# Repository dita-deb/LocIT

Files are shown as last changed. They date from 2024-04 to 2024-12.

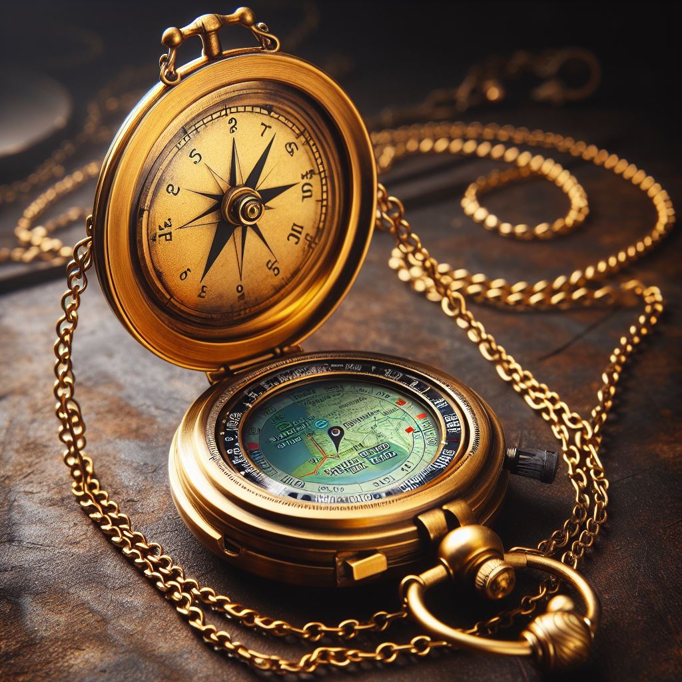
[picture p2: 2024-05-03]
3D Renders/Proposal/compasscam.jpg

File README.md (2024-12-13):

# LocIT
Senior Design Project 2024  

## Overview  
LocIT, short for "Location Integrated Tracker," is a wearable safety device designed to enhance the security and monitoring of vulnerable individuals, such as children and elderly users. This project addresses real-world safety concerns with an innovative combination of hardware and software, offering real-time location tracking, facial recognition, geofencing, and more.

## Features  
- **GPS Location Tracking**: Accurate updates every 30 seconds with a 3-foot precision.
- **Temperature Monitoring**: Prevents device overheating by triggering shutdowns of non-essential components.
- **Vibrating Alerts**: Provides real-time notifications for geofence breaches or caregiver messages.
- **Gyroscope and Accelerometer**: Detects sudden movements or falls, notifying caregivers instantly.
- **Facial Recognition**: Identifies individuals near the wearer for added safety insights.
- **Geofencing**: Sends alerts when the user exits predefined safe zones.
- **Companion App**: Supports live tracking, notifications, and settings customization via FlutterFlow.

## Hardware System  
- **Sensors Subsystem**: Includes GPS, temperature, battery monitor, accelerometer, and gyroscope.
- **Actuators Subsystem**: Utilizes a vibration motor for silent notifications.
- **Communications Subsystem**: Transfers data securely via MQTT to AWS IoT Core and DynamoDB.
- **Power Subsystem**: Powered by a rechargeable LiPoly battery with over 24 hours of operation.
- **Central Processing Unit**: Raspberry Pi Zero 2 W for managing data, algorithms, and communication.

## Software System  
- Python-based main algorithm managing data collection, device state, and communication.
- AWS integration for real-time data storage and retrieval. [Backend-Webserver](https://02fydzyygd.execute-api.us-east-2.amazonaws.com/LocITDynamoDBDisplay)
- Companion app (FlutterFlow) for monitoring and control.

## Encasing Design  
- Constructed from PLA filament with 2 mm thickness for strength and durability.
- Compact dimensions: 2 inches wide, 4 inches long, and 2 inches deep.
- Three lid variations:
  - **No Slots Lid**: For fully enclosed design.
  - **4 Vents Lid**: Balanced ventilation and enclosure.
  - **9 Vents Lid**: Maximum cooling for high-temperature environments.

## Results  
- **High Accuracy**: GPS provides precise location tracking within a 3-foot radius.
- **Reliable Notifications**: Geofence breaches and fall detection alerts are delivered promptly.
- **Extended Usability**: Optimized power management ensures operation over a full day.

## Improvements and Optimizations  
Future enhancements include:
- Advanced facial recognition models for diverse conditions.
- Improved companion app usability with push notifications.
- Additional sensors for expanded functionality (e.g., heart rate monitoring).

## Getting Started  
Visit the [LocIT GitHub Repository](https://github.com/dita-deb/LocIT) for source code, hardware schematics, and additional documentation.

## License  
This project is licensed under a custom license. Redistribution, modification, or commercial use is restricted without explicit permission from the contributors. See the [LICENSE](LICENSE) file for more details.

## Contributors  
- **Anindita Deb** (dita-deb)  
- **Zachary Ponder** (ponder-zachary)  
- **Avery Porter** (Averyp119)
- **Damisi Kayode** (DamisiKayode0312)

## Acknowledgments  
Special thanks to Professor Jeffrey L. Yiin at Kennesaw State University for guidance and mentorship throughout the project.

---

*LocIT: Bringing peace of mind to caregivers while ensuring the safety of their loved ones.*

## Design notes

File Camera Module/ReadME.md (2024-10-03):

# Camera Module
## Contains: camera imaging and processing 
### Materials:
- Pi Camera (2)
- RaspberryPi 3B+ or 4B
- Gyroscope
- Servo Motor
- 3D print Holder

### Proposal Folder
- Contains initial plans for the Senior Project Proposal
- Contains a work in progress facial expressions recognition files

### Facial Recognition for PC
- This contains the python code to run this model on Visual Studio Code

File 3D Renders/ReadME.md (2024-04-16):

# 3D Renders
## File contains:
- 3D models of pendant
- 3D models for Camera holder
- additional files..

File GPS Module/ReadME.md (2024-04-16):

# GPS Module
## Materials:
- TinyDuino Processor Board
  - Lithium Battery Support
- USB TinyShield
- Flash Memory TinyShield
- GPS TinyShield
- Mounting Kit
- Lithium Ion Polymer Battery - 3.7V 270mAh

## Website reference:
https://www.instructables.com/Tiny-GPS-Tracker/

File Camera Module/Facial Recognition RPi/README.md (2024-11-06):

# Facial Recognition on Raspberry Pi Zero 2W
## Materials 
- Pi Zero 2W
- PiCamera Module 3
Arducam Multi-Camera Header
## Set Up Environment
### Install Despendencies
- sudo apt update
- sudo apt install python3-opencv python3-picamera2
## Code Files
- face_taker.py
- face_train.py
- face_recognizer.py
## Notes:
### Key Adjustments Summary
- Replaced cv2.VideoCapture with Picamera2 to utilize the Raspberry Pi Camera Module.
- Modified the image capture and display logic to ensure compatibility with the Pi’s performance limitations.

- Performance Optimization: Reduce the detectMultiScale parameters (scaleFactor and minNeighbors) if performance is slow.
- Testing: Test each script independently to ensure smooth functionality. The Raspberry Pi Zero 2 W has limited power, so patience and optimizations may be necessary.

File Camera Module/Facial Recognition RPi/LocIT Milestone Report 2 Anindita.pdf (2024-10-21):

### LocIT Milestone #2 Report Update by Anindita Deb

Date: 09/21/2024 - 10/20/2024

Advancements Made Since Milestone 1
Facial Recognition Enhancements:
- Improved the facial recognition accuracy when detecting multiple faces:
- Initially, the system could only recognize one person in the frame.
- Progressed to tracking two people, but inaccurately. NotWorking_with_Sister.mov (https://kennesawedu.sharepoint.com/:v:/r/sites/Team-CpESeniorProject2024/Shared%20Documents/General/Milestone%20Presentations/Milestone%202%20Presentation/Not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)

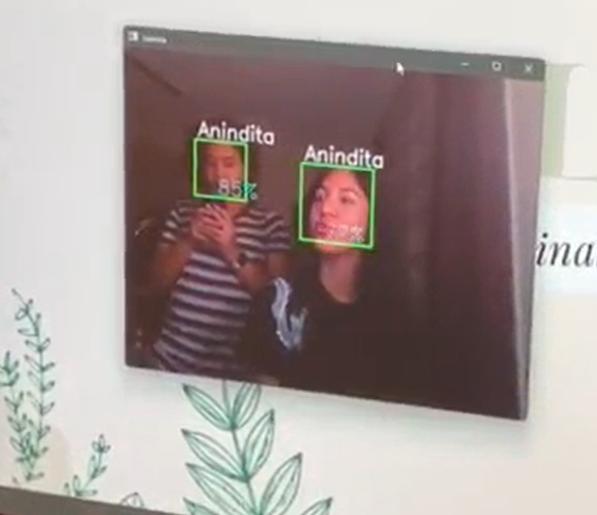
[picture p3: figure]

- Achieved successful tracking of two people. Working_with_Roommate.mov (https://kennesawedu.sharepoint.com/:v:/r/sites/Team-CpESeniorProject2024/Shared%20Documents/General/Milestone%20Presentations/Milestone%202%20Presentation/Wor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)

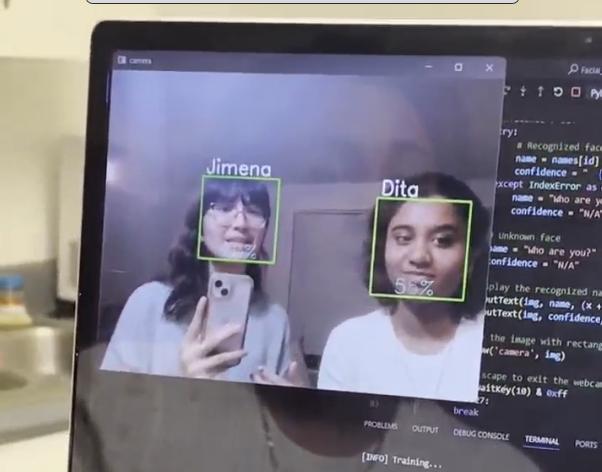
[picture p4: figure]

- Currently increased the capability to accurately track three people in a frame. zach-avery-dita.mov (https://kennesawedu.sharepoint.com/:v:/r/sites/Team-CpESeniorProject2024/Shared%20Documents/General/Milestone%20Presentations/Milestone%202%20Presentation/zac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)

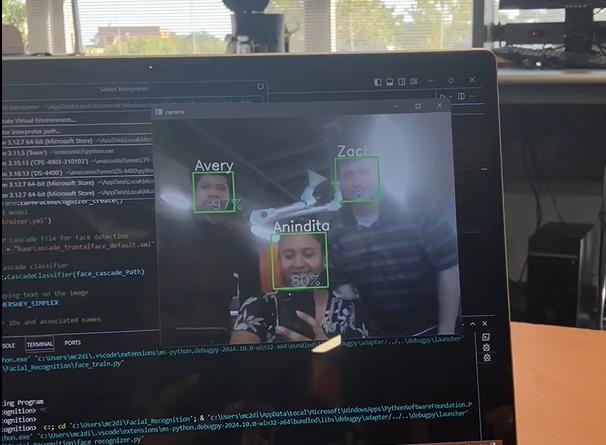
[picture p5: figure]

We tried it with the full group, but it was difficult to judge the accuracy of capturing all four of us in the frame. The pc camera was not catching everyone in the frame and would bounce between multiple people to track. I’ll cap it at 3 faces in frame being tracker when camera is on.
Camera Setup and Functionality:
- Configured the Raspberry Pi camera to detect faces and box them effectively.
- face-detection.mov (https://kennesawedu.sharepoint.com/:v:/r/sites/Team-CpESeniorProject2024/Shared%20Documents/General/Milestone%20Presentations/Milestone%202%20Presentation/fac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)
- face-detection-minimal-light.mov (https://kennesawedu.sharepoint.com/:v:/r/sites/Team-CpESeniorProject2024/Shared%20Documents/General/Milestone%20Presentations/Milestone%202%20Presentation/fac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)
- face-detection-darkness.mov (https://kennesawedu.sharepoint.com/:v:/r/sites/Team-CpESeniorProject2024/Shared%20Documents/General/Milestone%20Presentations/Milestone%202%20Presentation/fac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)
- Encountered issues with the labeling system, which is not functioning correctly.
- I suspect it’s the libraries not updating correctly per Raspberry Pi Model.
- I’ll be trying multiple existing models that have proven to work on Raspberry Pi to test and work it out in the coming milestone.
- The face_taker.py file is not yet operational for automatically capturing and saving the user’s face.
- The user needs to enter a name (which becomes a folder holding all images of that individual in the database)

- The Pi then asks the user to manually press a key on the keyboard to take a picture and it is saved to the designated folder
face-taker-not-automated.mov (https://kennesawedu.sharepoint.com/:v:/s/Team-CpESeniorProject2024/ESrZX5XtYEpOoALUHIoNt6YBmQBpAaYaH6LICQdui1YwaA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)

Integration of Models:
- Working on combining the facial recognition and expression monitoring models.
- Then placing it onto the pi camera.
- This integration process is taking additional time due to the need for compatible libraries for the Raspberry Pi.
- Once I’ve installed the models onto the pi, I’ll have it connected to AWS to active the camera remotely and store pictures off of the device to save storage.

Overview of Prior Work
As previously reported, the focus of the project includes this previous report:

### LocIT Milestone #1 Report by Anindita Deb

08/18/2024 - 09/20/24

Overview
I oversee the facial recognition software implemented in LocIT. Using various machine learning models, I aim to create a system capable of recognizing individuals and addressing multiple functionalities, including:
- Recognizing familiar faces
- Flagging unknown faces during significant interactions
- Identifying conditions that trigger a significant interaction
- Flagging certain facial expressions
- Angered/upsetting expressions could imply that the LocIT user is in a potentially unsafe situation
- Tracking negative expressions is a key feature being developed to alert the user to potential risks, improving situational awareness and safety
- Addressing additional issues like sleep/awakening conditions
- Limiting battery strain
- Handling privacy concerns

Facial Recognition Development
I’ve updated the code for this portion of the project to the GitHub Project page (https://github.com/dita-deb/LocIT/tree/main/Camera%20Module/Facial_Recognition_PC)

I wanted to eliminate the stress of collecting data through other means and inserting it into the model for training for the user. There’s a built-in file that will take snapshots of the user for 30 seconds (1 frame per second) to train the model to recognize the user.

Here is a break down of each individual file and its application to the overall model: Face_taker.py: Captures images of the target individual and stores them in the dataset for later use in training the model.
Face_train.py: Trains the facial recognition model using the images captured in Face_taker.py, allowing the system to recognize the individual’s face.
face_recognizer.py: Runs the trained facial recognition model, identifying individuals from the dataset in real-time or from new images.
names.json: Stores a mapping between each individual's name and their corresponding image data in the dataset.
haarcascade_frontalface_default.xml: A pre-trained Haar Cascade classifier that detects facial features (e.g., eyes, nose, mouth) to identify and classify faces for recognition.

The way that it displays a recognized face is by drawing a green box around the face and having the person labeled with a certain amount of confidence as shown below:

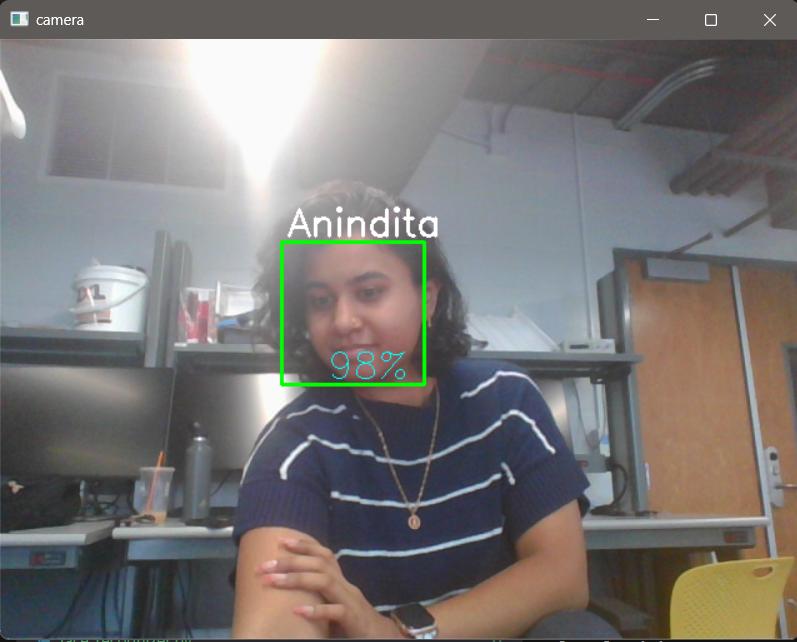
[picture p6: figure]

These just screen shots of a live video feed; I have a converter (video to image parser) not yet added to the model because there is yet to add a storage system to save these images and files for someone to view later. This will be a Milestone 2 issue, handling data and its storage and manipulation from the app.

Facial Expressions Development

I’ve updated the code for this portion of the project to the GitHub page (https://github.com/dita-deb/LocIT/tree/main/Camera%20Module/Proposal)

This phase of the project focuses on calculating a person’s eye gaze direction and blink rate, which form the initial part of addressing the expressions challenge.
These two factors—gaze direction and blink rate—are key indicators of whether a person is attentive or distracted. This classification helps determine how individuals around the LocIT wearer engage with them, affecting social interactions and spatial awareness.

The model uses Haar cascades to detect facial features, followed by PERCLOS for blink rate analysis, and geometric methods for gaze direction estimation.

Additionally, I plan to implement a system for tracking negative or threatening expressions. By flagging such expressions, the system can alert the wearer to potential risks, enhancing their safety and situational awareness. This is also not yet implemented to the hardware or Application yet, as it is a milestone 2 issue.

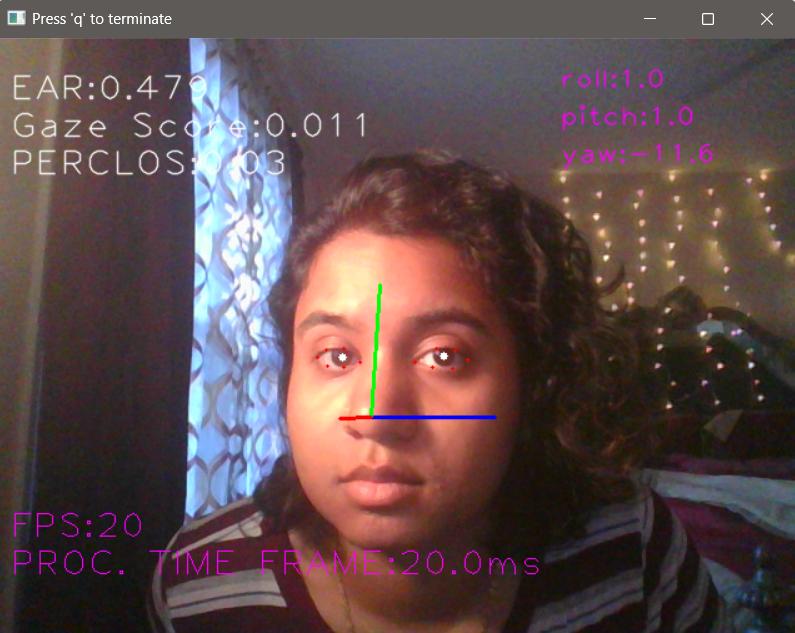
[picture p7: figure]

Here is a sample of what this model does:

The measurements here are displayed to check whether the model is working or not with “maths” that calculates tiredness/distraction/paying attention etc. This math is pre-built into the base model which I’m just changing some values to better check and flag certain expressions.

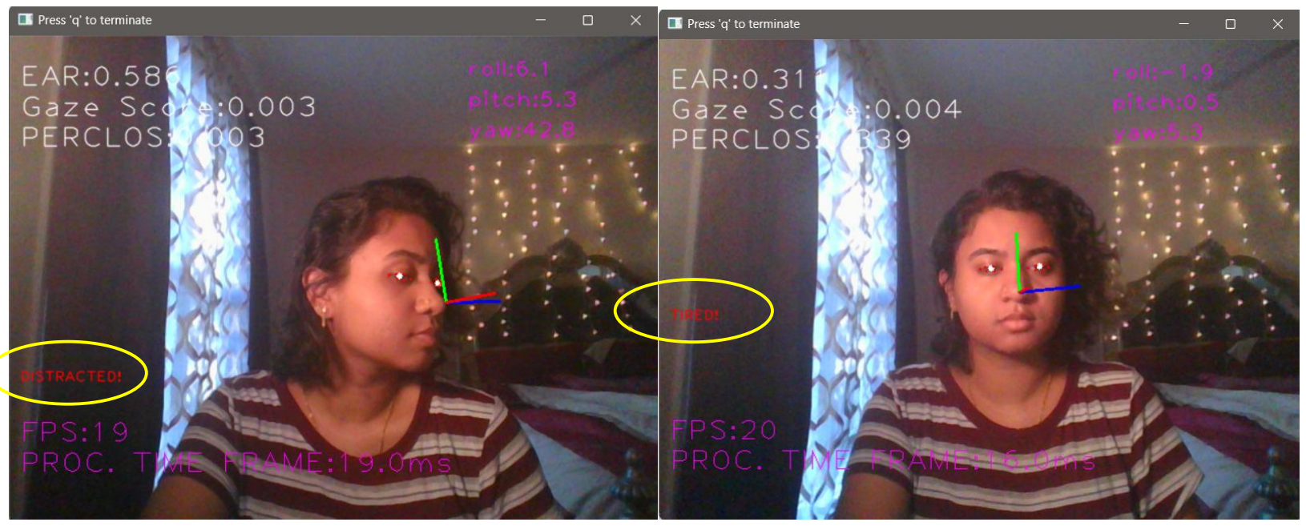
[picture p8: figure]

These images show a red text labeled “Distracted” and “tired” which can flag the interaction in different situations. Even if there is a person in front of the LocIT it would not flag the interaction as anything dangerous for the user or demand the individual be added to the dataset.
Software to Hardware Integration
The software to hardware implementations are in development as the model requires better storage for the images and video stream.

I have started using the Raspberry Pi 4B+, 2 PiCam Noir 3 Wide Module and ArduCam Header for implementation setup.

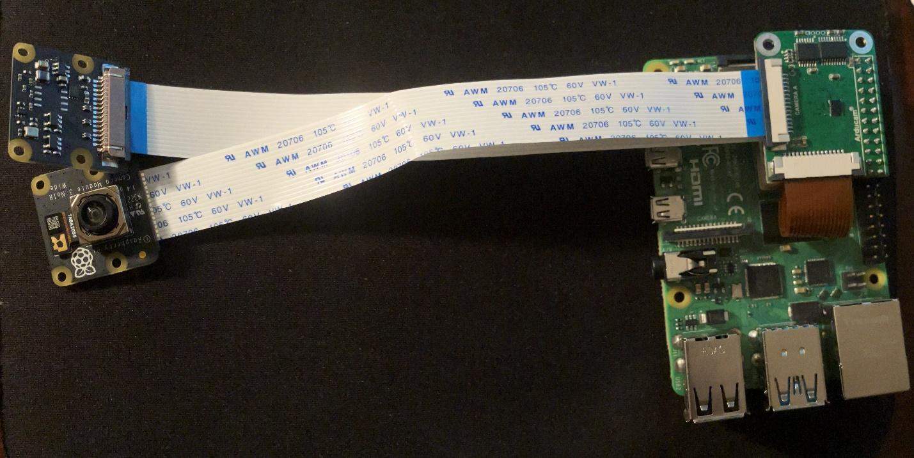
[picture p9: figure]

This is the set up, the cameras and header on the raspberry pi 4b+ are also compatible with the RaspberryPpi Zero 2 W. I’m using this board mainly as a way to quickly check the model working rather than than the Zero 2 board as a way to avoid any SW/HW issues that may come up when creating the final product.

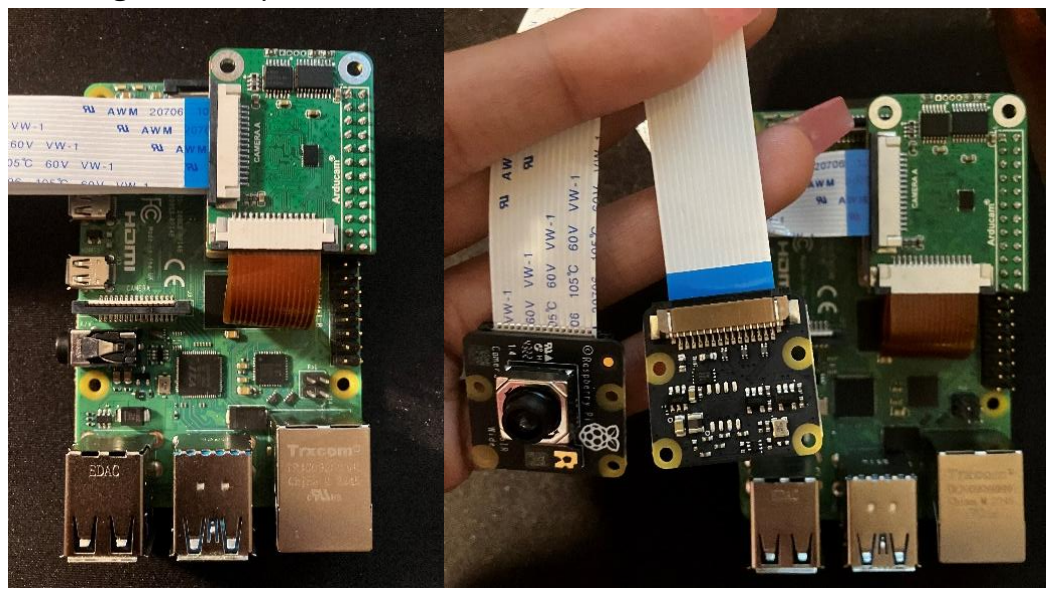
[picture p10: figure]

The ArduCam header allows me to connect 2 cameras to the Pi and have it checking whether there is a feed coming through one side or not to turn off a camera or not depending on the side that has live feed. The Pi on it’s own only allows one camera to operate at a time. This header allows for multiple cameras with a single component addition that is sized to fit the Pi Zero 2 W perfectly.

Issues/Challenges
IoT AWS implementation is going to be what our next milestone will encompass. The App development will also play a large part in data collection/storage/display for the next milestone. The integration portion of the hardware to software will be our biggest hurdle in the upcoming weeks.

Additional Information
Any additional information will be provided by the other reports.

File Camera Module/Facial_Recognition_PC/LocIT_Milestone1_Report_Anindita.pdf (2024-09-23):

### LocIT Milestone #1 Report by Anindita Deb

08/18/2024 - 09/20/24

Overview
I oversee the facial recognition software implemented in LocIT. Using various machine learning models, I aim to create a system capable of recognizing individuals and addressing multiple functionalities, including:
- Recognizing familiar faces
- Flagging unknown faces during significant interactions
- Identifying conditions that trigger a significant interaction
- Flagging certain facial expressions
- Angered/upsetting expressions could imply that the LocIT user is in a potentially unsafe situation
- Tracking negative expressions is a key feature being developed to alert the user to potential risks, improving situational awareness and safety
- Addressing additional issues like sleep/awakening conditions
- Limiting battery strain
- Handling privacy concerns

Facial Recognition Development
I’ve updated the code for this portion of the project to the GitHub Project page (https://github.com/dita-deb/LocIT/tree/main/Camera%20Module/Facial_Recognition_PC)

I wanted to eliminate the stress of collecting data through other means and inserting it into the model for training for the user. There’s a built-in file that will take snapshots of the user for 30 seconds (1 frame per second) to train the model to recognize the user.

Here is a break down of each individual file and its application to the overall model: Face_taker.py: Captures images of the target individual and stores them in the dataset for later use in training the model.
Face_train.py: Trains the facial recognition model using the images captured in Face_taker.py, allowing the system to recognize the individual’s face.
face_recognizer.py: Runs the trained facial recognition model, identifying individuals from the dataset in real-time or from new images.
names.json: Stores a mapping between each individual's name and their corresponding image data in the dataset.
haarcascade_frontalface_default.xml: A pre-trained Haar Cascade classifier that detects facial features (e.g., eyes, nose, mouth) to identify and classify faces for recognition.

The way that it displays a recognized face is by drawing a green box around the face and having the person labeled with a certain amount of confidence as shown below:

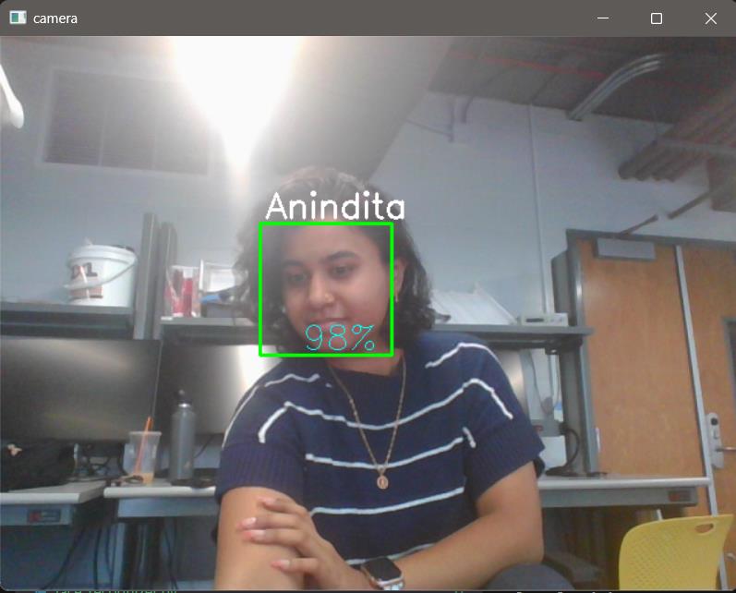
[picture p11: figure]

These just screen shots of a live video feed; I have a converter (video to image parser) not yet added to the model because there is yet to add a storage system to save these images and files for someone to view later. This will be a Milestone 2 issue, handling data and its storage and manipulation from the app.

Facial Expressions Development
I’ve updated the code for this portion of the project to the GitHub page (https://github.com/dita-deb/LocIT/tree/main/Camera%20Module/Proposal)

This phase of the project focuses on calculating a person’s eye gaze direction and blink rate, which form the initial part of addressing the expressions challenge.
These two factors—gaze direction and blink rate—are key indicators of whether a person is attentive or distracted. This classification helps determine how individuals around the LocIT wearer engage with them, affecting social interactions and spatial awareness.

The model uses Haar cascades to detect facial features, followed by PERCLOS for blink rate analysis, and geometric methods for gaze direction estimation.

Additionally, I plan to implement a system for tracking negative or threatening expressions. By flagging such expressions, the system can alert the wearer to potential risks, enhancing their safety and situational awareness. This is also not yet implemented to the hardware or Application yet, as it is a milestone 2 issue.

Here is a sample of what this model does:

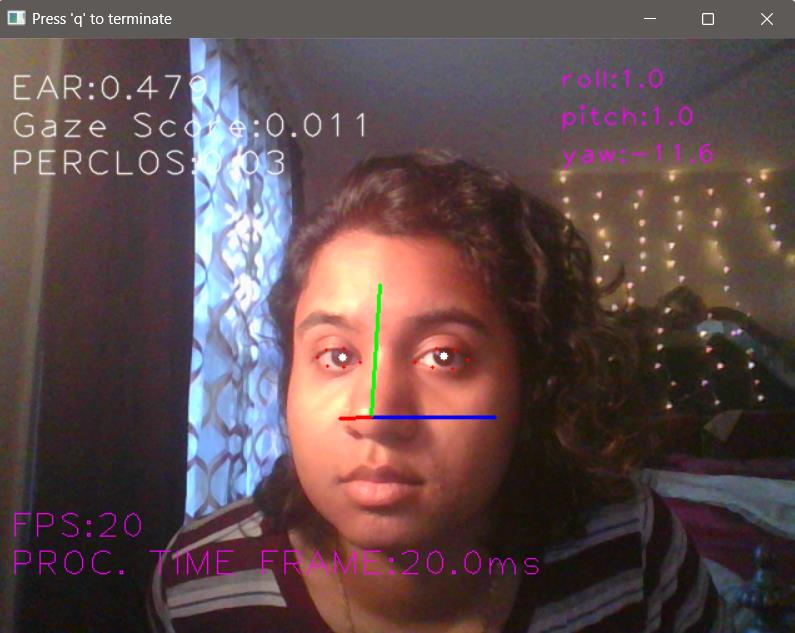
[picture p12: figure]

The measurements here are displayed to check whether the model is working or not with “maths” that calculates tiredness/distraction/paying attention etc. This math is pre-built into the base model which I’m just changing some values to better check and flag certain expressions.

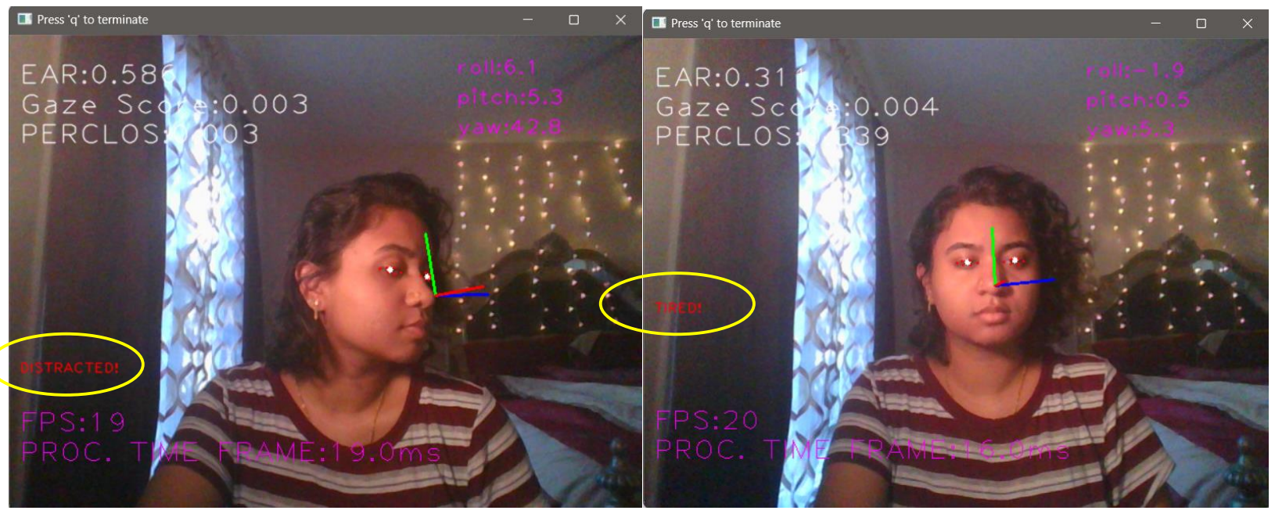
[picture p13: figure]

These images show a red text labeled “Distracted” and “tired” which can flag the interaction in different situations. Even if there is a person in front of the LocIT it would not flag the interaction as anything dangerous for the user or demand the individual be added to the dataset.

Software to Hardware Integration
The software to hardware implementations are in development as the model requires better storage for the images and video stream.

I have started using the Raspberry Pi 4B+, 2 PiCam Noir 3 Wide Module and ArduCam Header for implementation setup.

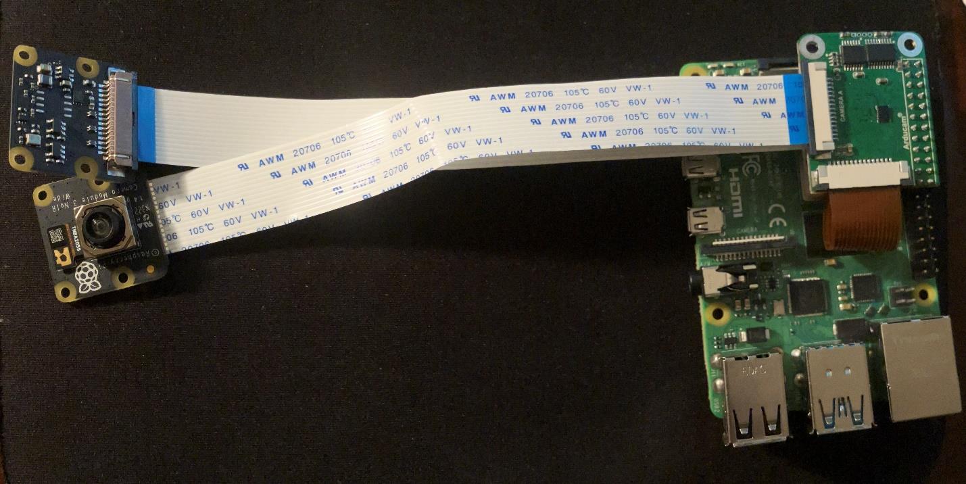
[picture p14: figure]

This is the set up, the cameras and header on the raspberry pi 4b+ are also compatible with the RaspberryPpi Zero 2 W. I’m using this board mainly as a way to quickly check the model working rather than than the Zero 2 board as a way to avoid any SW/HW issues that may come up when creating the final product.

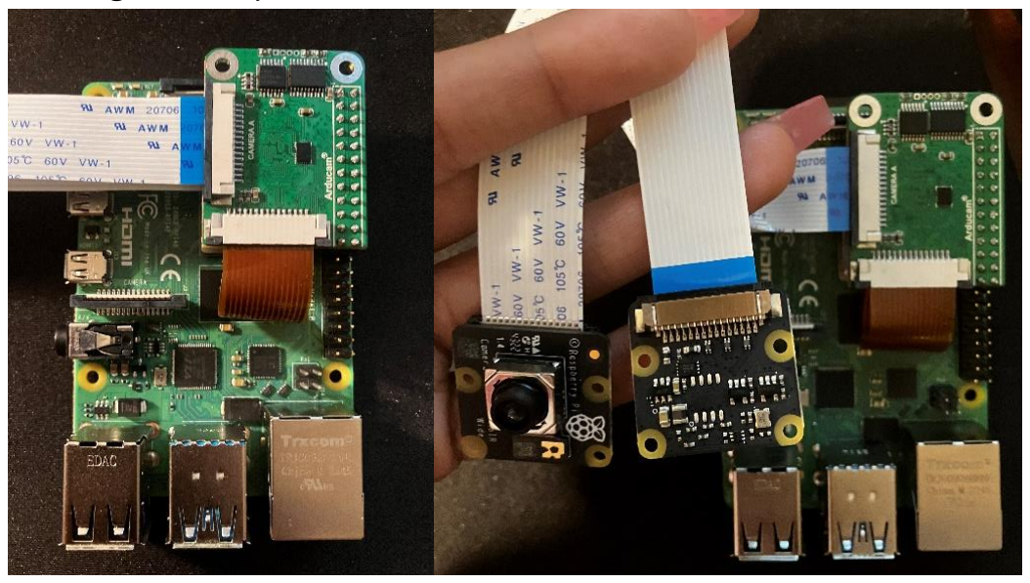
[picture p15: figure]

The ArduCam header allows me to connect 2 cameras to the Pi and have it checking whether there is a feed coming through one side or not to turn off a camera or not depending on the side that has live feed. The Pi on it’s own only allows one camera to operate at a time. This header allows for multiple cameras with a single component addition that is sized to fit the Pi Zero 2 W perfectly.

Issues/Challenges
IoT AWS implementation is going to be what our next milestone will encompass. The App development will also play a large part in data collection/storage/display for the next milestone. The integration portion of the hardware to software will be our biggest hurdle in the upcoming weeks.

Additional Information
Any additional information will be provided by the other reports.

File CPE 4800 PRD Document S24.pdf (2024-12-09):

## CPE 4800 - Senior Design Proposal, Spring 2024

# Product Requirements Document

## LocIT

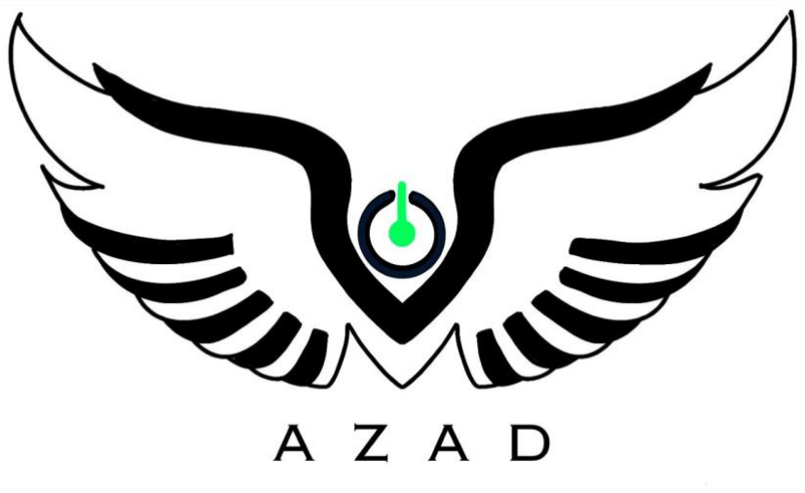
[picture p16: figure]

## Rev. Number: Revision D

## Date: April 15, 2024

## Electrical and Computer Engineering

## Kennesaw State University

Faculty: Dr. Jeffrey L Yiin

Product Requirements Document

## Revision History

Name | Date | Reason For Changes | Version
AZAD | 03-31-2024 | Initial Release | Rev. - Draft
AZAD | 04-15-2024 | Updated minor changes to the following: revision history, I. Introduction, and II. Product specifications Major changes to the following: Table of Contents, List of Figures, List of Tables, III. System Architecture, Bill of Materials, Product Requirements, and Bibliography | Rev. - A
AZAD | 10-21-2024 | Bluetooth functionality has been added to the feature set. Ultraviolet sensors have been removed from the design due to excessive procurement lead times. | Rev. - B
AZAD | 10-23-2024 | Updated product requirements to remove any instances of ultraviolet sensors and adding Bluetooth requirements. | Rev. - C
AZAD | 11-16-2024 | Adjusted product requirements to account for changes that were made to the prototype given the scope of the project. | Rev. - D

## Table of Contents

## List of Figures

Total List of Figures

Figure Description | Section of PRD | Starting Page
Concept Prototype Renders | II. Introduction | Page 8
System Hardware Diagram | III. System Architecture | Page 15
Power Management Subsystem | III. System Architecture | Page 16
Camera Subsystem Diagram | III. System Architecture | Page 17
Software App Block Diagram | III. System Architecture | Page 18
Location Tracking Swimlane | III. System Architecture | Page 20
Facial Recognition Swimlane | III. System Architecture | Page 21
Geofencing Swimlane Diagram | III. System Architecture | Page 23
PCB Subsystem Diagram | IV. Product Requirements | Page 26
Microcontroller Subsystem | IV. Product Requirements | Page 28
Mobile App Subsystem Diagram | IV. Product Requirements | Page 29

## List of Tables

Current List of Tables

Table Title | Section of PRD | Starting Page
Functional Requirements | II. Product Specifications | Page 11
Bill of Materials | III. System Architecture | Page 23

## I. Introduction

1. High-level product description
This project aims to address a pressing need for families with young children and elderly members who need the accessibility and ease of locating their loved ones in real time. The proposed solution is a wearable tracker designed specifically for these demographics.
The primary goal is to provide families with peace of mind by offering a lightweight, rechargeable tracker that operates independently of cellular devices. This ensures constant access to the location of loved ones.
2. Key product feature sets
This project plans to include the following features in order to accommodate most of the target issues for the demographic.
1) Precision tracking allows the device to accurately track the user's location in real-time.
2) Solar-Powered recharging utilizes solar power ensuring sustainability and reduces dependency on traditional charging methods.
3) Cellular device independence allows the tracker to function autonomously, eliminating the need for a connected cellphone.
4) Facial recognition enhances security and assurance by identifying individuals who encounter the user.
5) Distance Monitoring will track distances covered by the user, providing insights into their movements.
6) Geofencing allows users to set boundaries within which the wearer can move, with alerts triggered if these boundaries are breached.
3. Value proposition to the customers
For families with young children and elderly members, peace of mind is invaluable. Our wearable tracker offers a solution tailored to your needs, providing constant access to the location of your loved ones without the need for a cellphone. With precision tracking and solar-powered recharging, you can rest assured knowing their whereabouts are always within reach. Our device goes beyond mere location tracking, incorporating facial recognition for added security and distance monitoring to keep you informed about their activities. Plus, with customizable geofencing, you can establish safe boundaries and receive alerts if they wander too far. Experience the reassurance of knowing your loved ones are safe and secure, no matter where they may be, with our innovative tracker.
4. Target Market Analysis
1. Target market size: annual shipment units and total sales revenue (worldwide or US market). There were nearly half a billion smart wearable devices sold worldwide in 2023. This includes over 305 million smartwatch units alone. The total revenue in the previous year equated to 45 billion dollars according to Statista.com¹
. The wearable
smart device market is expected to continue to grow as the post COVID pandemic

1 Statista Website: Historical Trends 2023, https://www.statista.com/topics/1556/wearable-technology/#dossier-chapter2

pushed lots of people to be more health oriented. This includes all markets, especially the Asia-Pacific one where people utilizing smart devices are expected to rise from 76% to over 94% by the end of the decade.
2. Existing competition: The smart wearable market is considered fragmented, by mordorintelligence.com²
, which is defined as a market that is highly competitive with many different competitors; however, there is no single entity taking the lion’s share of the sales. The two main competitors are the Apple AirTag and the Tile tracker. The strength of Apple is its name. Everyone everywhere knows the name Apple at this point, and purchasing items from them is always safe with a guaranteed high-quality product. Their weakness though is they prefer to push items only compatible with their products. In fact, it took a major court case in Europe to get them to transition away from the Lightning cable and to the more common USB-C for their charging ports. Tile is mainly used to keep track of items like a wallet, car keys, etc., but could be repurposed to track individuals. The weakness though, much with Apple, is that they require the user to also possess a cell phone which is not the purpose of our product. We strive to provide a service that allows people to keep track of the location of their loved ones whether they are carrying a phone with them or not.
5. Visual representation of the product
Conceptually we have a variety of options to consider for the compact and design of the product. First is a necklace with a pendant with two cameras on either side, which would turn on depending on the side that receives light. The arm band is at a good height on the body to be worn and for the camera to still capture images, though it is not as compact or extremely discrete. It also has no guarantee of staying put in one direction as the user would move around so that would make implementing a set number of cameras harder. A pin or brooch would be a nice alternative if the user does not mind reattaching the device to new outfits every time. A fanny pack/sling design would be stable and not require two cameras for image capturing; however, it is not as discrete or as compact as we would like it to be.

Taking in account the factors and issues with all the options available, we have settled with a pendant design that would include a camera near the hinge. A combination of ultraviolet sensors and a gyroscope would be capable of determining orientation of the pendant and turn on the appropriate front-facing camera on either side.

2 Mordor Intelligence, Wearable Trackers Market Share & Growth: https://www.mordorintelligence.com/industry-reports/wearable-technology-market

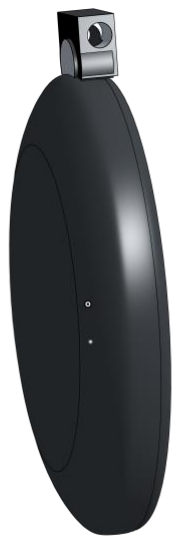
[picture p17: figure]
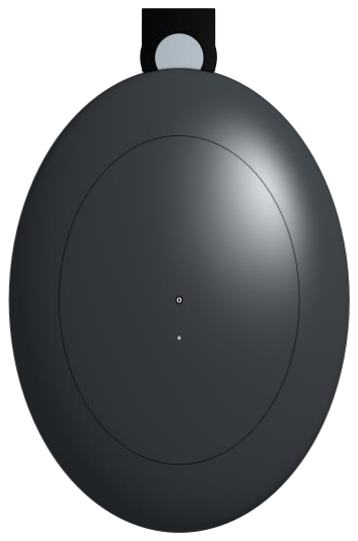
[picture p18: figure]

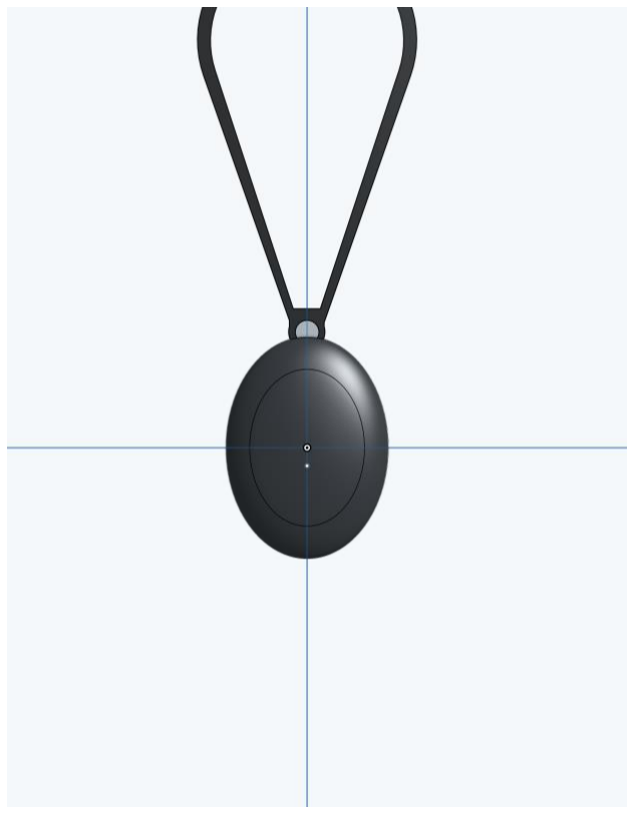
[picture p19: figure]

## II.Product Specifications

Requirement
ID
Description | Category | Priority

FNC-001 | The wearer tracker shall give an accurate location of the wearer within 3 feet of the wearer’s actual position. | Functional | Must Have
OPR-001 | The wearable tracker shall update the location at a regular interval of every 30 seconds. | Operational | Must Have
OPR-002 | The wearable tracker shall have a camera that is always capable of orienting towards the front and ensures image capturing in that direction. | Operational | Must Have
FAF-001 | The tracker will be able to measure the total distance travelled by the wearer over a given period of a day. | Fit and Form | Must Have
FNC-002 | The camera on the wearable tracker shall have facial recognition capabilities with the ability to recognize familiar faces. | Functional | Must Have
FNC-003 | The tracker will be integrated with voice assistance that can speak to the trackable wearer. | Functional | Nice to Have
FNC-004 | Users shall be able to set up or disable geocentric virtual boundaries for the wearer. | Functional | Must Have
FNC-005 | The application must send the host phone holder a notification if the wearable tracker leaves these boundaries. | Functional | Must Have
FNC-006 | The application shall send a notification to the host phone if the | Functional | Must Have

| battery level of the wearable tracker is below 20% remaining.
ENV-001 | The wearable tracker shall be chargeable using direct plug-in charging capabilities. | Enviromental | Must Have
ENV-002 | The wearable tracker shall prioritize Bluetooth connectivity over Wi-Fi when available, to optimize power efficiency and extend battery life. | Enviromental | Nice to Have
INT-001 | The companion app shall be able to be navigated by a user needing less than an hour of training on the app. | Interface | Must Have
INT-002 | The companion app shall utilize push buttons that allow the user to toggle between the various options (ie. Location, camera, geo-boundaries, notifications, settings) | Interface | Must Have
FNC-007 | The tracker shall utilize encryption techniques to securely connect between itself and the user’s companion application. | Functional | Must Have
NFC-001 | The tracker shall operate reliably under uncertain conditions such as change of habit, weather, or location. | Non-Functional | Must Have
PER-001 | The tracker must be able to handle simultaneous connections and data processes with a greater than 97% efficiency rate. | Performance | Must Have
NFC-002 | The host phone shall have the ability to add up to three wearable trackers on the companion application. | Non-Functional | Must Have

PER-002 | The companion app shall be able to connect and work seamlessly with both Android and Web devices. | Performance | Must Have
FAF-003 | The tracker shall be durable and resistant to water, dust, and fall protection. | Fit-and-Form | Must Have
FAF-004 | The wearable tracker shall feature a rectangular design with rounded corners to enhance safety and minimize the risk of injuries or accidents. | Fit-and-Form | Must Have
FAF-005 | The tracker shall weigh less than 15 grams³ to allow it to be worn comfortably. | Fit-and-Form | Must Have
FNC-008 | The tracker will allow for two-way communication between the companion app and wearer. | Functional | Nice to Have
INT-003 | The companion app will be accessible by supporting multiple different languages, including Spanish and French. | Interface | Nice to Have
INT-004 | The companion app will allow for customization, including changing the color palette. | Interface | Nice to Have
OPR-003 | The wearable tracker can monitor temperature to inform the wearer of dangerous outdoor conditions. | Operational | Nice to Have
OPR-004 | The wearable tracker will have the ability to monitor temperature to | Operational | Nice to Have

3 Avg. Weight of Necklace: https://fetchthelove.com/blogs/necklace/how-much-does-a-necklace-weigh-in-oz

| place the system in critical mode in the event of overheating.
FAF-006 | The wearable tracker will have a vibration notification system if another individual tries to communicate with the wearer. | Fit to Form | Nice to Have
OPR-005 | The wearable tracker will be able to go into low battery mode, which turns off all features except location and boundary tracking. | Operational | Nice to Have
FNC-009 | The wearable tracker will be able to store medical history information in a medical emergency. | Functional | Nice to Have
III. | System Architecture
Diagrams of System’s Functionality and External Interfaces:

System Hardware Block Diagram:

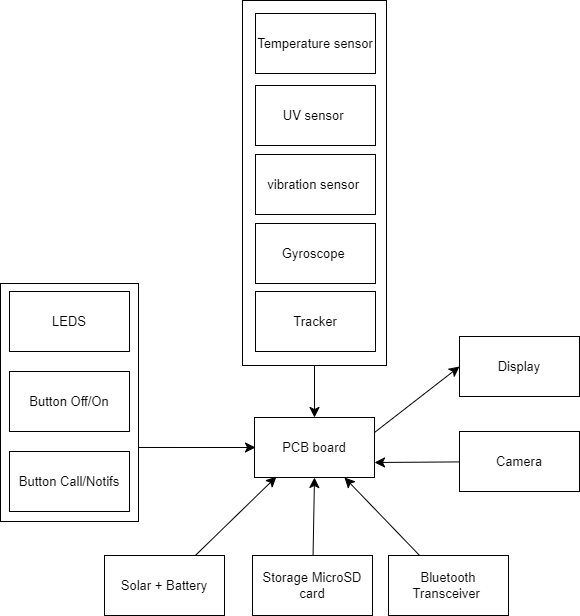
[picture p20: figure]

Power Management Subsystem: This subsystem includes the rechargeable battery, solar battery/panel, and software application to notify the user of the health of the battery system as well as defining the necessary function operations on low power mode.

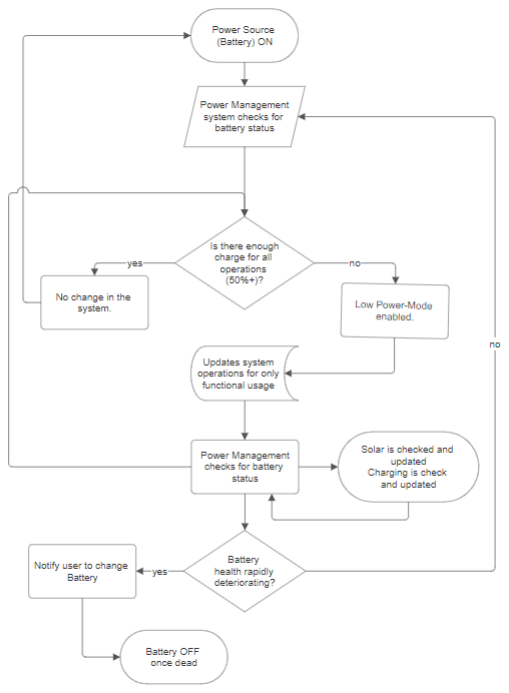
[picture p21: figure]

Camera Subsystem: This subsystem would include the Cameras, UV sensor, Gyroscope, and Battery Management system. The application is also included in the process for updating images to the application.

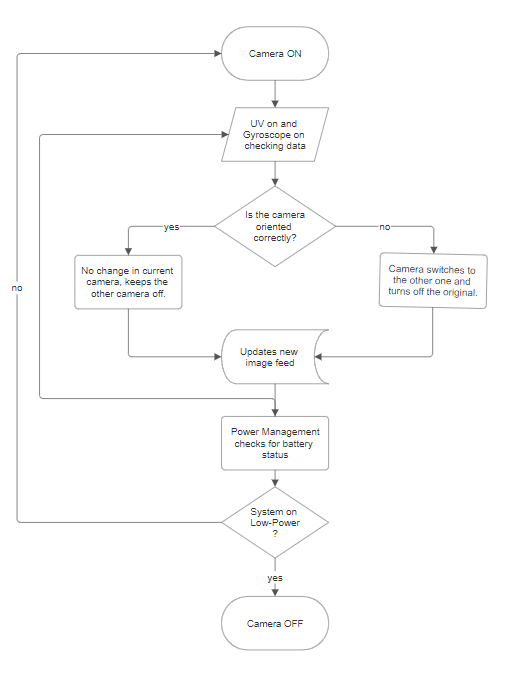
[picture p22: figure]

Software Application Block Diagram:

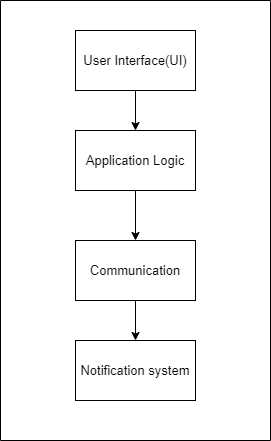
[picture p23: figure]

Analysis of three use cases:
This includes narrative descriptions and Swim Lane diagrams to demonstrate interactions across different system components.

Use Case #1: Location Tracking and Safety Monitoring
Scenario: Being able to track the location of the person wearing the tracker utilizing another smart device. The wearer does not have to carry a phone themselves as the necklace should suffice.

Actor: Parent/Caregiver

Goal: Utilize the location tracking capabilities of the LocIT wearable tracker to monitor the whereabouts and ensure the safety of a loved one.

Preconditions:

- The LocIT tracker is activated, charged, and securely worn by the individual.
- The parent/caregiver has the companion mobile application installed and configured.

Steps:

1. The parent/caregiver opens the LocIT mobile application.
2. The application displays the real-time location of the tracked individual on a map interface.
3. Geofencing boundaries are set to define safe zones or restricted areas for the individual's movement.
4. The parent/caregiver receives alerts if the individual breaches the predefined boundaries or moves beyond a specified distance.
5. Facial recognition alerts notify the parent/caregiver when unfamiliar individuals approach the tracked individual.
6. The parent/caregiver can remotely access historical location data to track the individual's movements over time.

Postconditions:

- The parent/caregiver feels reassured about the safety and well-being of the tracked individual.

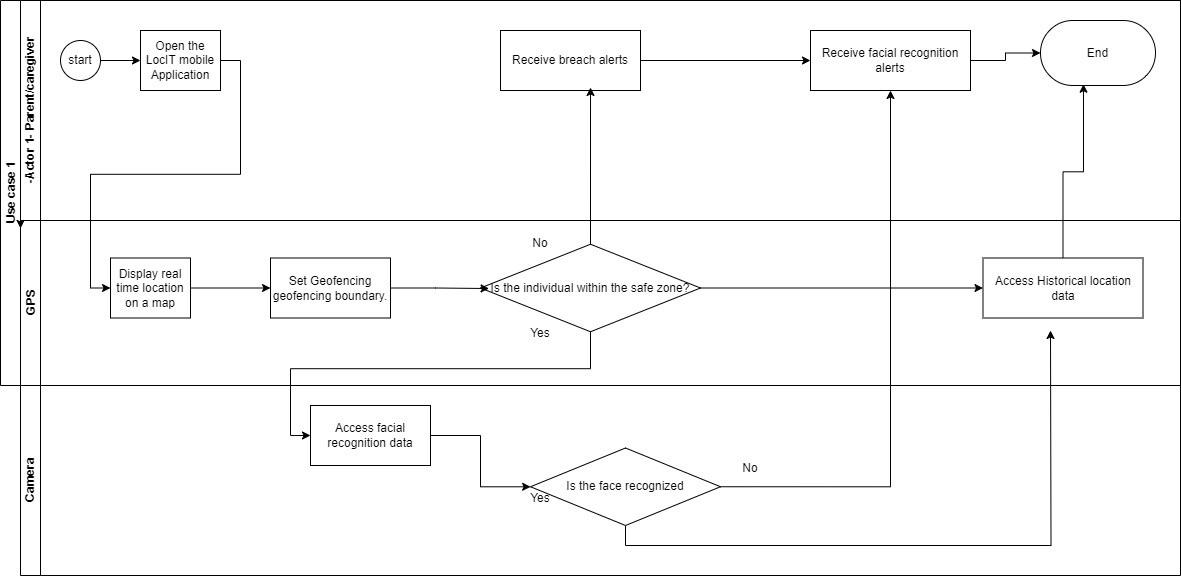
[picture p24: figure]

Use Case #2: Facial Recognition Security
Scenario: A camera is attached to the wearable tracker. It must be attached in a way that the camera is always facing forward towards the people interaction with the wearer. This may be difficult with a necklace without a gyroscope. We are considering implementing either two cameras on either side of the pendant and having a gyroscope and/or UV detect the pendant's orientation.

Actor: User/Caregiver

Goal: Enhance security by utilizing the facial recognition camera feature of the LocIT wearable tracker.

Preconditions:

- The LocIT tracker is equipped with facial recognition capabilities and is properly configured.
- The user or caregiver has access to the companion mobile application.

Steps:

1. The user or caregiver accesses the LocIT mobile application.
2. The application provides an option to view facial recognition alerts.
3. The facial recognition camera captures the image of an individual approaching the user.
4. The captured image is analyzed by the facial recognition algorithm.
5. If the individual is recognized as authorized (e.g., a family member), no action is taken.
6. If the individual is unrecognized or flagged as unauthorized, the user or caregiver receives an immediate alert.
7. The alert includes details such as the time of the encounter and the image of the unrecognized individual.

Postconditions:

- The user or caregiver receives timely notifications of potential security threats, enabling proactive measures to ensure safety.

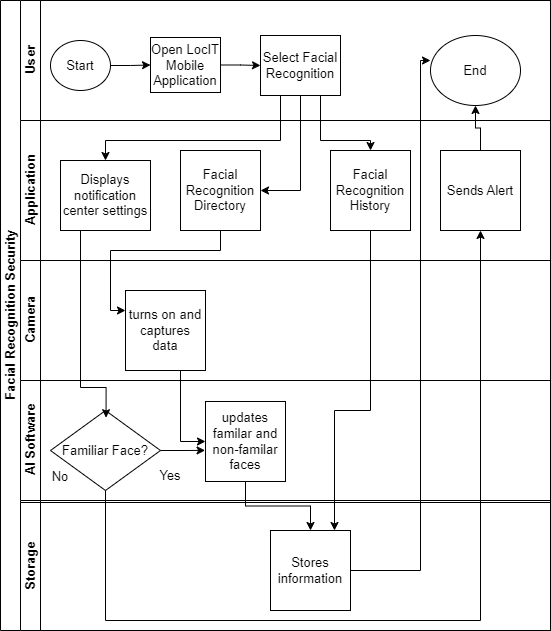
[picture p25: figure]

Use Case #3: Geofencing
Scenario: A user wants to ensure their loved one stays within a designated safe area while outside. They utilize the geofencing feature of the LocIT wearable tracker to monitor the wearer’s movements and receive alerts if they stray beyond the predefined boundaries.

Actor: User/Caregiver

Goal: Utilize geofencing to monitor the child's location and receive alerts if they leave the designated safe area.

Preconditions:

- The LocIT tracker is equipped with geofencing capabilities and is properly configured.
- The parent/user has access to the companion mobile application.

Steps:

1. The parent/user accesses the LocIT mobile application.
2. They navigate to the geofencing settings within the application.

3. The parent defines the safe area where the user can go by setting up a geofence on the map.
4. Once the geofence is set, the application confirms the boundaries have been established.
5. As the user wears the LocIT tracker and moves within the defined area, their movements are tracked by the GPS.
6. If the user moves towards the edge of the designated area, nearing the geofence boundary, the application detects this movement.
7. When the user breaches the geofence boundary, the application triggers an immediate alert to the parent/user.
8. The alert notifies the parent/user of the breach, providing details such as the time of the incident and the child's last known location within the safe area.

Postconditions:

- The parent/user receives real-time alerts when the child breaches the predefined geofence boundaries.
- The geofencing feature enables the parent/user to monitor the child's movements and take appropriate actions to ensure their safety.
- The parent/user feels reassured knowing they can remotely monitor the child's location and intervene if necessary, enhancing peace of mind.

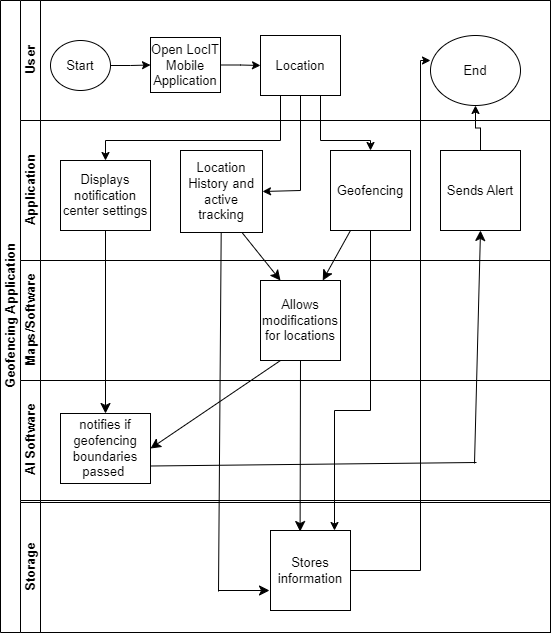
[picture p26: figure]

Bill of Materials

A preliminary Bill of Materials (BOM) listing key components and estimated costs, providing an early insight into the project's scope and scale.

Component | Description | Quantity | Unit Cost (USD) | Total Cost (USD)
STM 32 Microcontroller | Central processing unit for device operations | 1 | 15 | 15
GPS Module | Provides location tracking capabilities | 1 | 65 | 65
Camera Module | For photographic functions and facial recognition | 1 | 25 | 25

Speaker | Outputs audio for alerts and communications | 1 | 4 | 4
Wireless Communication Module | Enables data transfer and remote communication | 1 | 10.39 | 10.39
Vibration Motor | Provides haptic feedback | 1 | 5 | 5
Environmental Sensors | Measures UV, temperature, etc. | 2 | 6 | 12
Battery Management System | Manages battery charging and power distribution | 1 | 8 | 8
PCB (Printed Circuit Board) | Supports and connects all electronic components | 1 | 20 | 20
Rechargeable Battery | Powers the device | 1 | 12 | 12
Total Estimated Cost | | | | 176.39
IV. | Product Requirements

Subsystem #1: Physical Wearable Tracker

Description:
The physical wearable tracker subsystem comprises the tangible device worn by the user to track their location, monitor environmental conditions, and facilitate communication with the companion app. It incorporates various sensors, communication modules, user interface elements, and power management components to fulfill its functionalities. Additionally, the physical wearable tracker is designed to be durable, comfortable to wear, and resistant to environmental factors such as water and dust.

Key components:

- Location tracking module
- Camera module
- Facial recognition software
- Voice assistance integration
- Geofencing module
- Battery management system
- Two-way communication system
- Environmental sensors (UV, temperature)
- Vibration notification system
- Medical history storage module

Interfaces:
Internal Interfaces:
- Connection between GPS module and microcontroller for location data processing
- Integration of environmental sensors with data acquisition circuitry
- Communication between microphone, speaker, and wireless communication module for voice communication
- Interface between display screen/indicators and microcontroller for status feedback
- Connection between user input interfaces (buttons, touch-sensitive panels) and microcontroller for user interaction
External Interfaces:
- Wireless communication with companion app for data exchange and remote control
- Charging port for power supply and battery recharging

Exceptions:
1. Exception for Requirement: The PCB board may not accommodate additional components if they exceed the physical dimensions or power constraints specified for the wearable tracker system.
2. Exception for Requirement: If specific environmental sensors are not available or feasible for integration, alternative methods for environmental data acquisition may be considered.
3. Exception for Requirement: In cases where voltage regulators cannot be implemented due to space constraints or power consumption limitations, alternative power management solutions may be explored to ensure stable operation of the system.

Subsystem Diagram:


Subsystem #2: PCB Board

Description:
The PCB, or Printed Circuit Board, subsystem serves as the hardware platform for integrating and connecting various electronic components of the wearable tracker system. It provides functionalities such as power distribution, signal processing, data storage, and communication between different modules within the system. Additionally, the PCB board ensures the efficient operation and interaction of the hardware components, enabling the wearable tracker to perform its designated functions reliably.

Key components:
- GPS module for location tracking
- Environmental sensors (e.g., temperature, UV exposure)
- Microphone and speaker for voice communication
- Display screen or indicators for status feedback
- Buttons or touch-sensitive interfaces for user input
- Wireless communication module (e.g., Bluetooth, Wi-Fi)
- Battery for power supply
- Enclosure or casing for protection and comfort
- Charging port for recharging the battery
- Circuitry for signal processing and data management

Interfaces:
Internal Interfaces:
- Connection with various electronic components (e.g., sensors, MCU, memory)
- Integration with power management circuitry for efficient power distribution
- Communication interfaces for data exchange between modules
- Interface with connectors for external peripherals
External Interfaces:
- Interaction with wearable components (e.g., sensors, LEDs)
- Connection with battery and charging port for power supply
- Interface with companion app and wearable tracker for data exchange

Exceptions:
1. Exception for Requirement: The PCB board may not accommodate additional components if they exceed the physical dimensions or power constraints specified for the wearable tracker system.
2. Exception for Requirement: If specific environmental sensors are not available or feasible for integration, alternative methods for environmental data acquisition may be considered.
3. Exception for Requirement: In cases where voltage regulators cannot be implemented due to space constraints or power consumption limitations, alternative power management solutions may be explored to ensure stable operation of the system.
Subsystem Diagram:


Subsystem #3: Mobile App/Software

Description:
The mobile, companion app subsystem serves as the user interface for interacting with the wearable tracker system. It provides functionalities such as setting up geofencing boundaries, receiving notifications, accessing location data, managing device settings, and facilitating two-way communication with the wearer. Additionally, it supports features like language customization, color palette customization, and integration with third-party devices.

Key components:
- User interface (UI)
- Geofencing setup module
- Notification system
- Location tracking display
- Settings management module
- Two-way communication interface
- Language customization feature
- Color palette customization feature
- Integration with third-party devices

Interfaces:
Internal Interfaces:
- Interaction with the wearable tracker subsystem for data exchange (e.g., location data, battery status)
- Integration with geofencing setup module for boundary configuration
- Communication with notification system for alert delivery
- Connection with two-way communication interface for wearer interaction
- Interaction with settings management module for configuration adjustments External Interfaces:
- Connectivity with wearable tracker system for data exchange
- Integration with third-party devices for interoperability

Exceptions:
- Exception for Requirement: If supporting multiple languages significantly impacts app performance or development complexity, prioritization of language support may be adjusted based on user demographics.
- Exception for Requirement: In cases where the storage of medical history information poses privacy or regulatory concerns, alternative methods for emergency data retrieval may be considered, ensuring compliance with applicable regulations.

Subsystem Diagram:


## Bibliography

Cuttingedgecircuit.com. “The Integration of Facial Recognition in Wearable Devices.” Cutting Edge Circuit, 11 Mar. 2024, cuttingedgecircuit.com/the-integration-of-facial-recognition-in-wearable-devices/.

“A Guide to Writing Requirements.” A Guide to Functional Requirements (with Examples), 11 Apr. 2022, www.nuclino.com/articles/functional-requirements.

Horia Maior, Assistant Professor, et al. “Smart Rings’ Ultra-Precise Movement Tracking Takes Wearable Technology to the next Level.” The Conversation, 20 Mar. 2024, theconversation.com/smart-rings-ultra-precise-movement-tracking-takes-wearable-technology-to-the-next-level-225604.

Laricchia, Federica. “Topic: Wearables.” Statista, 10 Jan. 2024, www.statista.com/topics/1556/wearable-technology/#dossier-chapter2.

Wearable Technology Market Size & Share Analysis - Industry Research Report - Growth Trends, 2024, www.mordorintelligence.com/industry-reports/wearable-technology-market. (http://www.mordorintelligence.com/industry-reports/wearable-technology-market)

Wood, Steven. “How Much Does a Necklace Weigh in Oz?” Fetchthelove Inc., Fetchthelove Inc., 5 Oct. 2022, fetchthelove.com/blogs/necklace/how-much-does-a-necklace-weigh-in-oz.

1. Doe, John. "The Importance of Referencing in Academic Writing." Journal of Academic Writing, vol. 5, no. 2, 2019, pp. 15-28.
2. Smith, Alice. How to Write a Research Paper. Academic Press, 2022

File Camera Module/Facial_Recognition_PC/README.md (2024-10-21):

# Facial Recognition on VSCode
## Milestone #1 Demo

### Overview:
This folder contains the code used for facial recognition tasks, specifically capturing, training, and recognizing faces.

### Week 6 Code:
#### File Descriptions:
Face_taker.py: Captures images of the target individual and stores them in the dataset for later use in training the model.

Face_train.py: Trains the facial recognition model using the images captured in Face_taker.py, allowing the system to recognize the individual’s face.

face_recognizer.py: Runs the trained facial recognition model, identifying individuals from the dataset in real-time or from new images.

names.json: Stores a mapping between each individual's name and their corresponding image data in the dataset.

haarcascade_frontalface_default.xml: A pre-trained Haar Cascade classifier that detects facial features (e.g., eyes, nose, mouth) to identify and classify faces for recognition.

### Videos:
NotWorking_with_Sister-ezgif com-crop
This video is from when the model was not working and giving an error when tracking multiple faces to the same name.

Working_with_Roommate-ezgif com-crop
This video is from the model starts recognizing two people accurately.

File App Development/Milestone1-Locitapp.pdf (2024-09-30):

User Application for Milestone 1 by Damisi Kayode

Progress Report: Lockit App Development
Overview
I’ve made solid progress on the Lockit app by developing key features in FlutterFlow while using Figma to map out the UI/UX. Which has helped create a more intuitive, userfriendly experience.
FlutterFlow Development
1. Built Core Pages
I’ve developed the main app pages, like the home screen, settings, and profile, making sure they align with the hardware features of the Lockit device.
2. Added Important Features
I integrated a bottom navigation bar and the Google Maps widget which would be integrated with the GPS of our necklace giving users easy access to location tracking and geofencing.
3. Focused on UI Design
I set up the interface with a clean and simple layout, including a five-icon navigation bar for quick access to key features, ensuring the app is easy to navigate.
Figma for UI/UX Planning
1. Created a Site Map in Figma
To get a better understanding of the app flow, I made a site map in Figma. This helped me plan how different pages connect and improve the overall user journey.
2. Drafted UI/UX Designs
Using Figma, I sketched out the first draft of the app’s design. This gave me a clearer picture of how the app would look and feel, ensuring it’s both functional and visually appealing.
Conclusion
By combining FlutterFlow for development and Figma for design planning, I’ve been able to build an app that can be easily integrated with the hardware but also userfriendly. There’s still more to do, but these steps have laid a strong foundation for the Lockit app.
Link to the app review on flutterflow: https://app.flutterflow.io/share/locitdraft-nt59sr


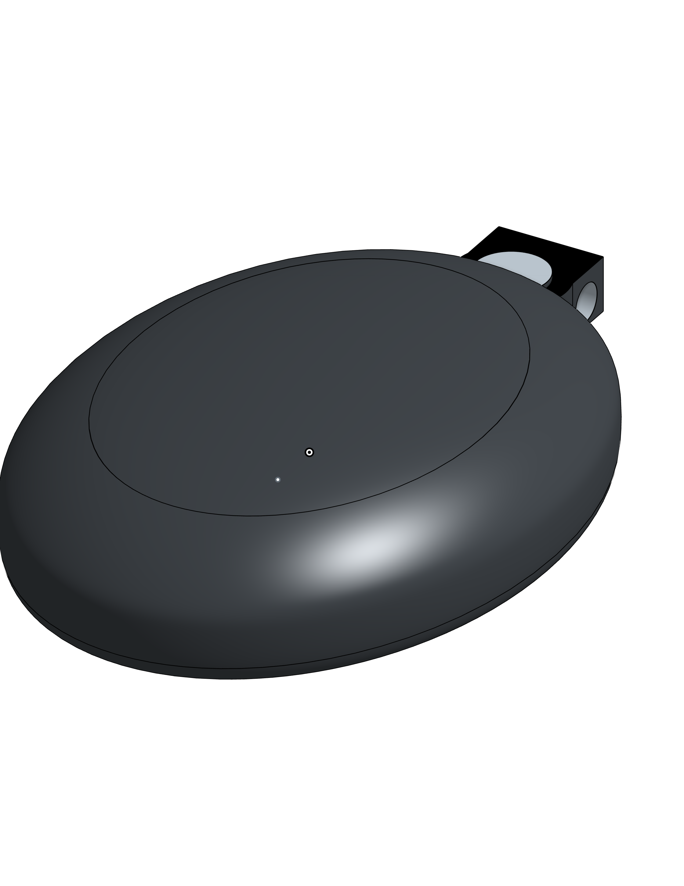
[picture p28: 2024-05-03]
3D Renders/Proposal/Part Studio 1 (6).png

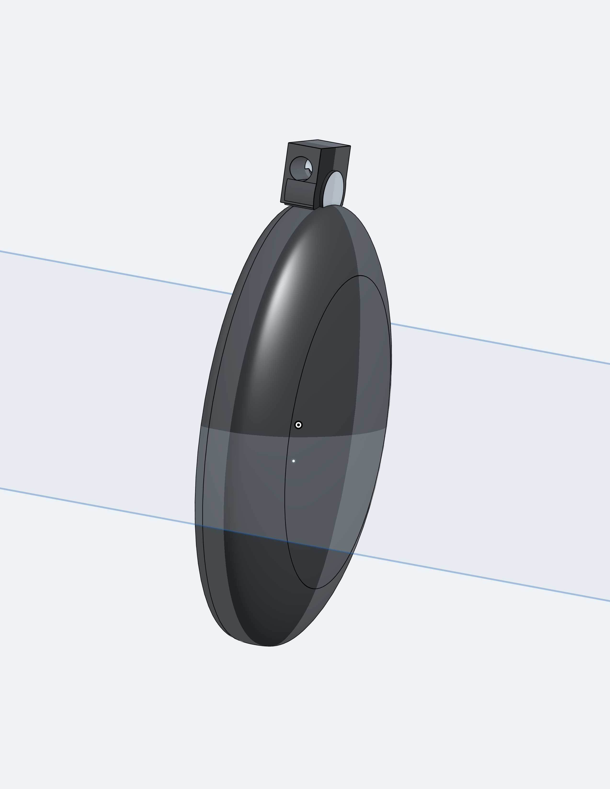
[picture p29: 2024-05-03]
3D Renders/Proposal/Part Studio 1 (3)_1.png

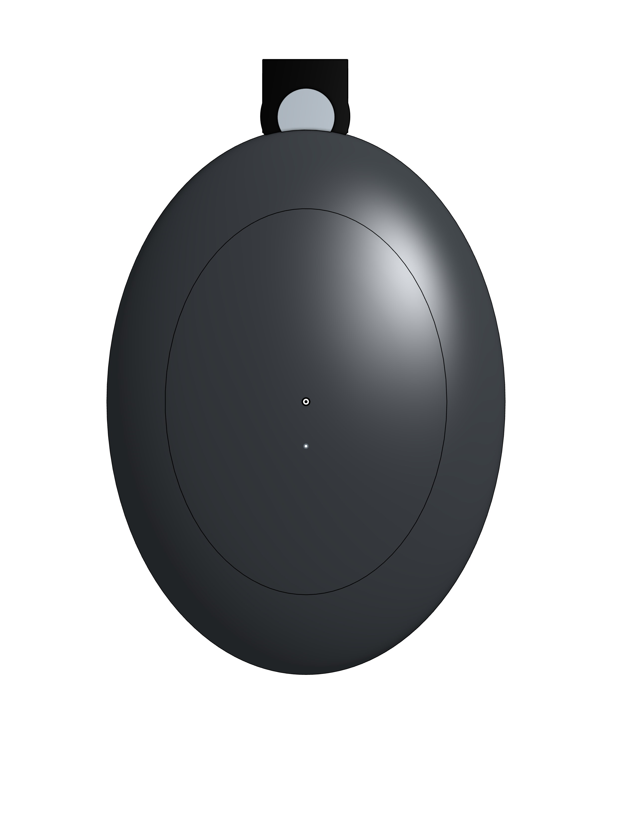
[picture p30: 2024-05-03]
3D Renders/Proposal/Part Studio 1 (4)_1.png

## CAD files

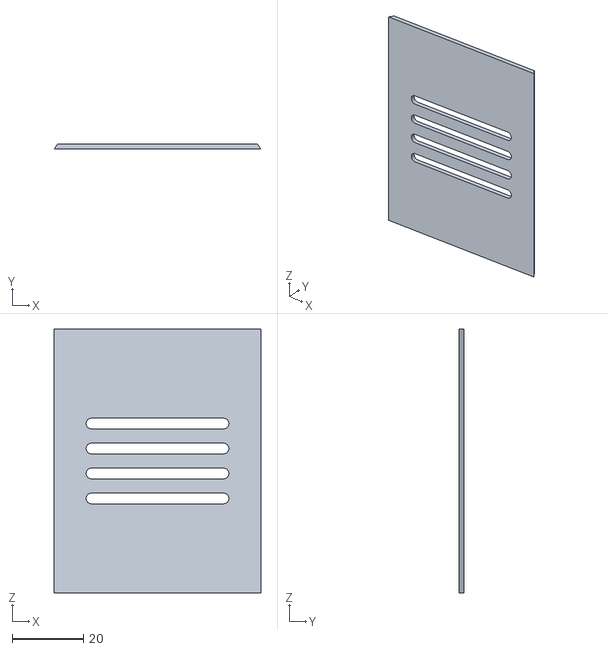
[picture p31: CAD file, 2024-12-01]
3D Renders/Design/Version 5/Anindita Senior Design (Lid with Slots V2).STL
58.0 x 1.50 x 74.0

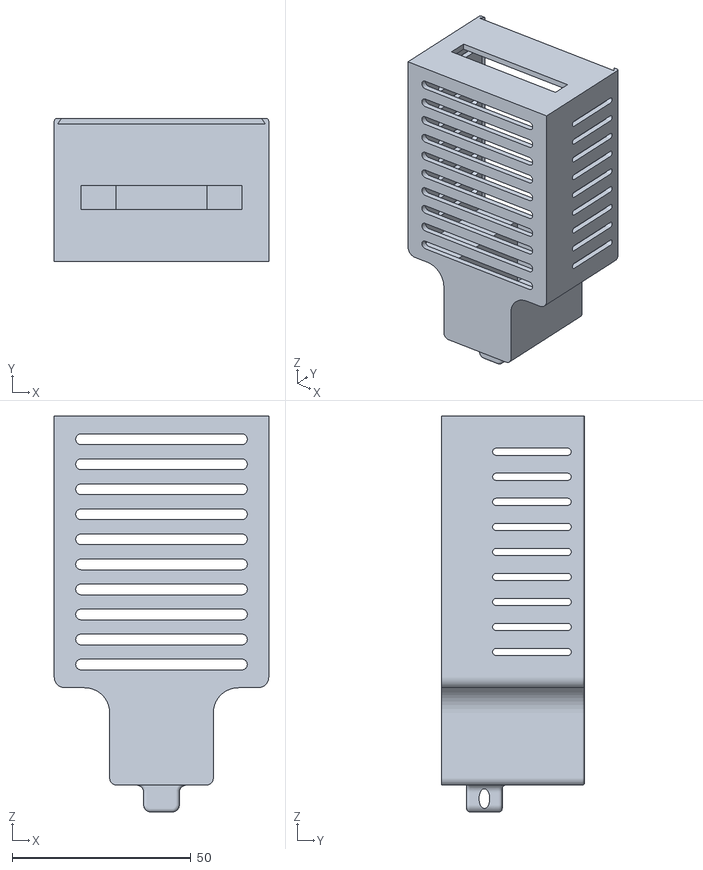
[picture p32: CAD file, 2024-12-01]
3D Renders/Design/Version 5/Anindita Senior Design (Body)_1.STL
60.0 x 40.0 x 110.8

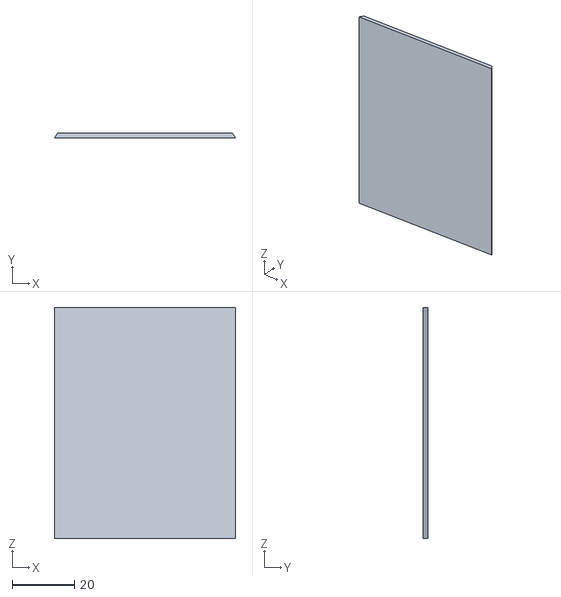
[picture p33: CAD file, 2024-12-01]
3D Renders/Design/Version 5/Anindita Senior Design (Lid)_1.STL
58.0 x 1.50 x 74.0

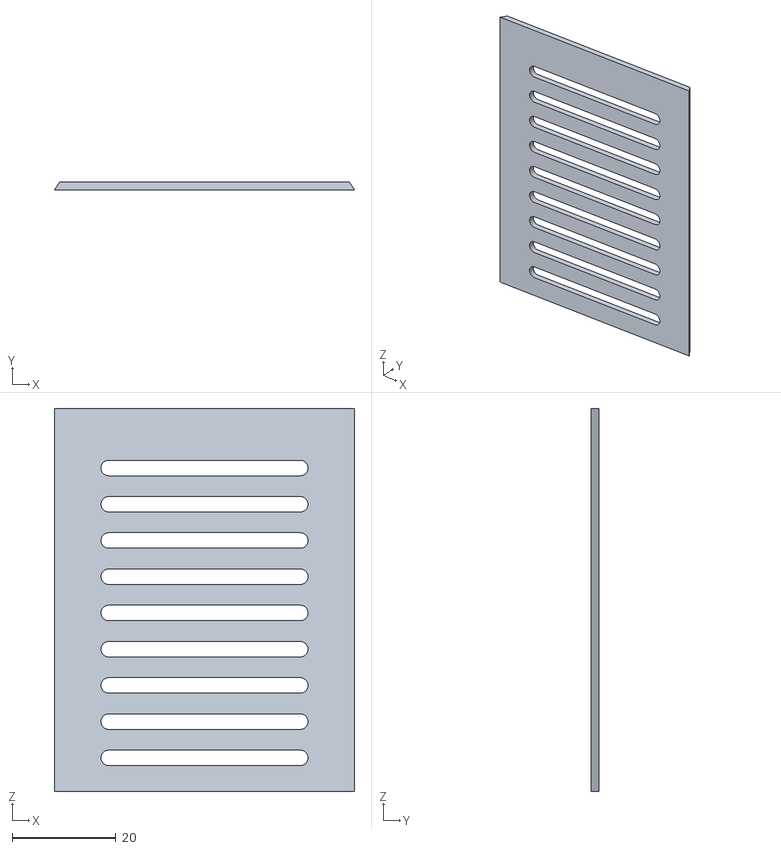
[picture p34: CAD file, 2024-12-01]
3D Renders/Design/Version 5/Anindita Senior Design (Lid with Slots).STL
58.0 x 1.50 x 74.0

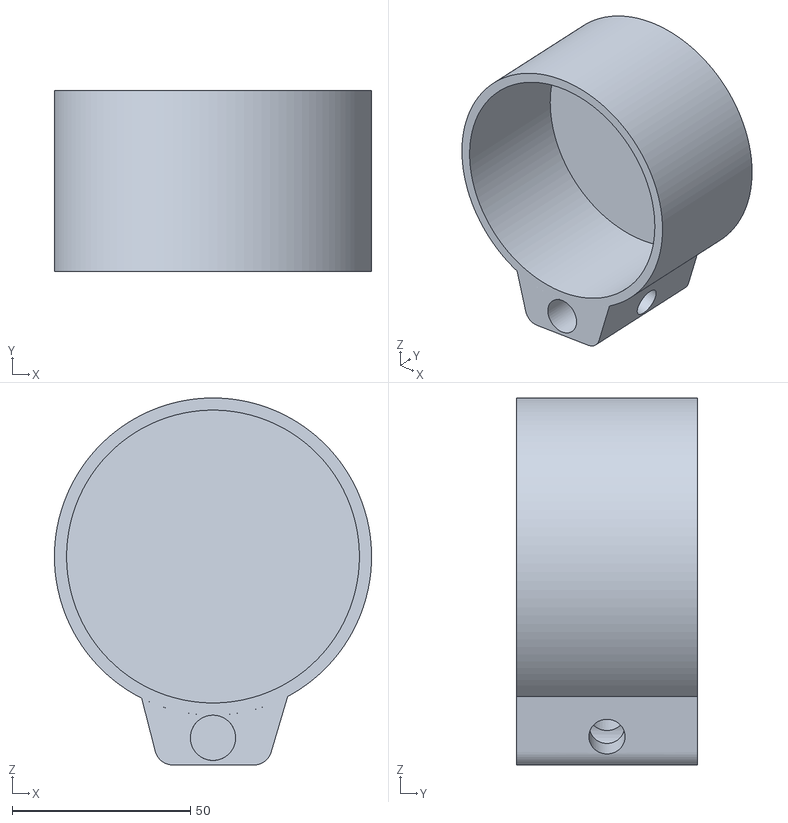
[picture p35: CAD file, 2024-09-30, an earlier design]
3D Renders/Design/Version 1/KAYODE_DAMISI_LOCITCOVER-version1.stl
88.9 x 50.8 x 102.9

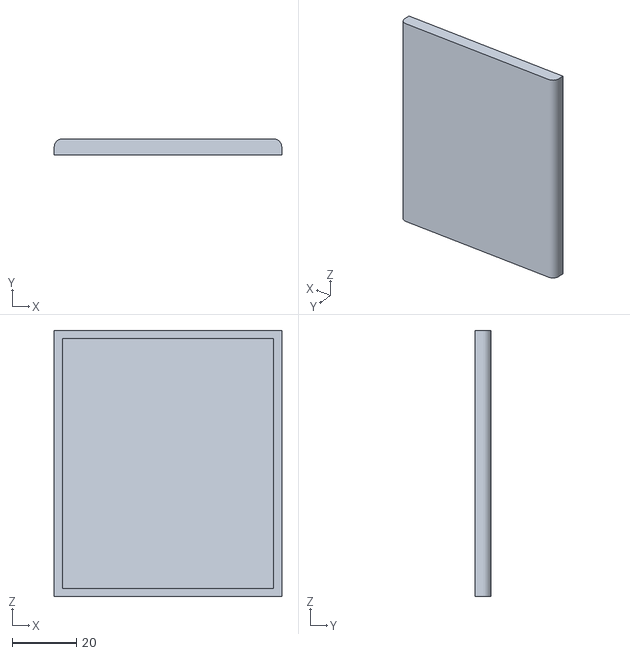
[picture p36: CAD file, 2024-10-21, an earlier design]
3D Renders/Design/Version 2/KAYODE_OLUWADAMISI_LOCITCOVER-V2.stl
70.6 x 5.08 x 82.5

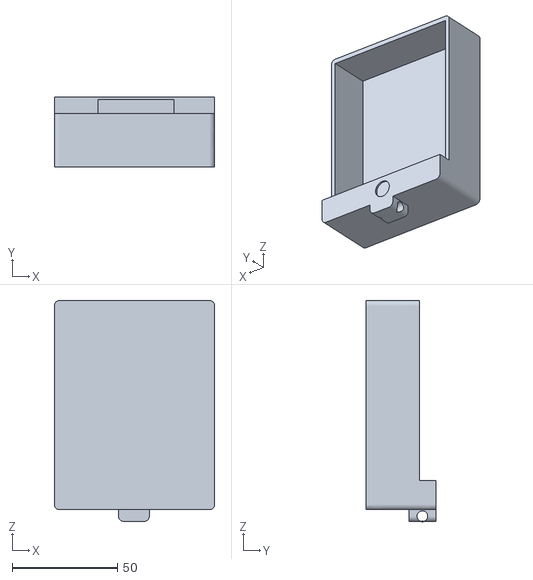
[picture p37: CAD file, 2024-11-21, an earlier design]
3D Renders/Design/Version 3/Kayode_Oluwadamisi_Locit_draft2 v4.stl
76.2 x 33.0 x 105.0

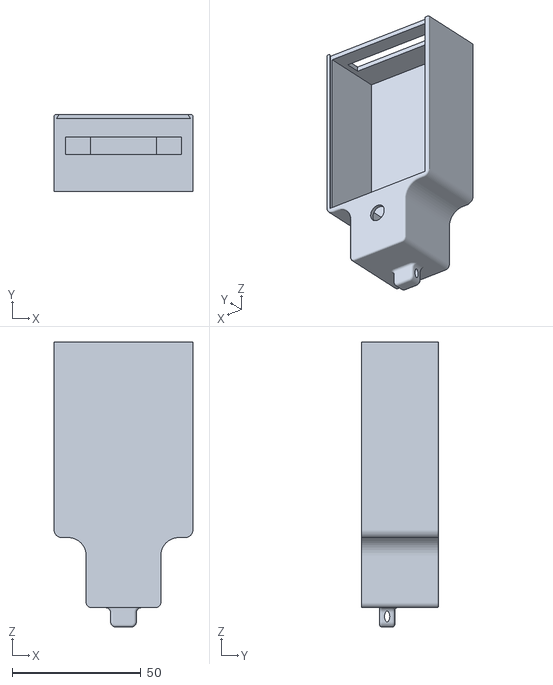
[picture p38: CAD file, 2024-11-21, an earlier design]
3D Renders/Design/Version 4/Anindita Senior Design (Body).STL
54.0 x 30.0 x 110.8

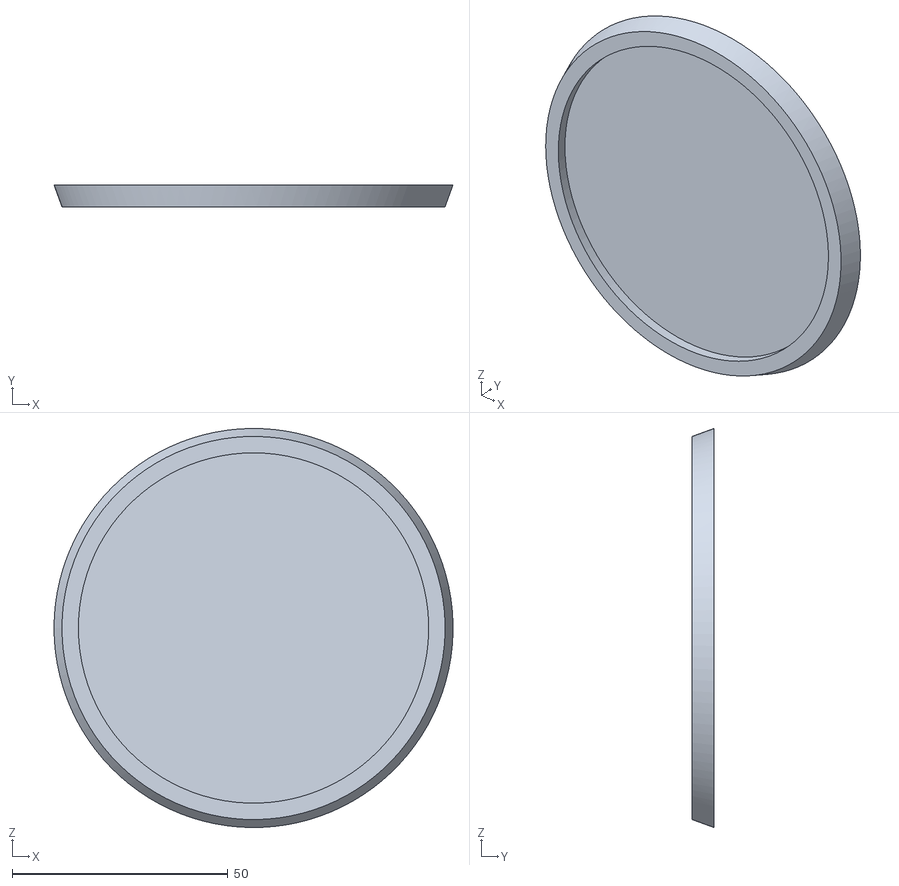
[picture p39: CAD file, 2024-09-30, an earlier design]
3D Renders/Design/Version 1/KAYODE_DAMISI_LOCITBODY-version1.stl
92.6 x 5.08 x 92.6

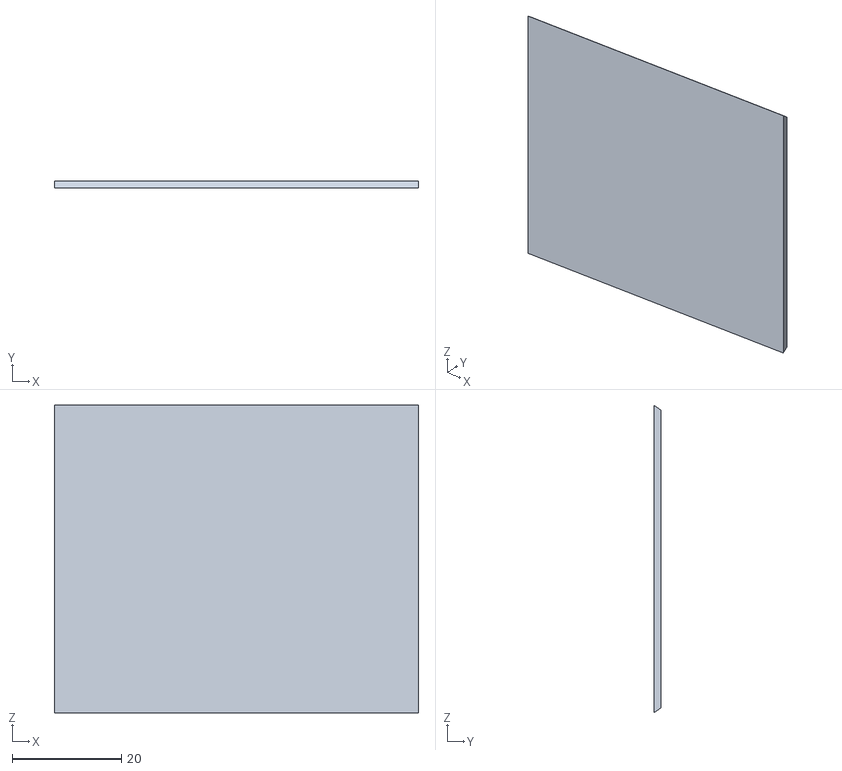
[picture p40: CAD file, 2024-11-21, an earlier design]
3D Renders/Design/Version 3/Kayode_OluwadamisiLocITLid_v1_.stl
66.6 x 1.30 x 56.3

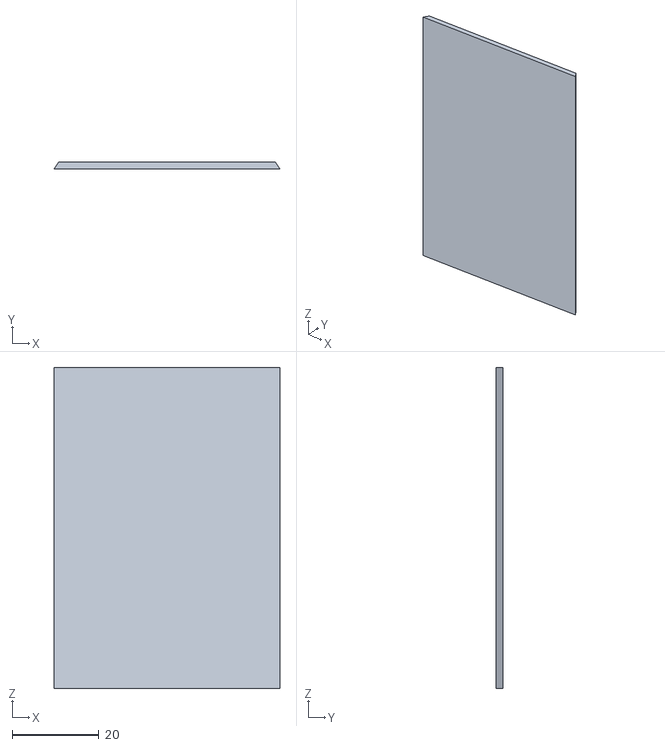
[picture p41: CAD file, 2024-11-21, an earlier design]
3D Renders/Design/Version 4/Anindita Senior Design (Lid).STL
52.0 x 1.50 x 74.0

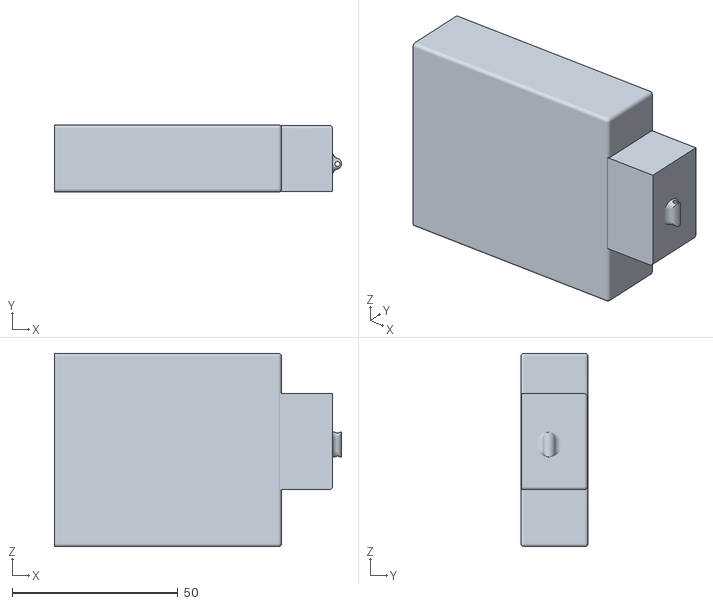
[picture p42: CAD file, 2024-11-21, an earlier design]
3D Renders/Design/Version 3/Kayode_Oluwadamisi_Locitbody_ v1.stl
86.7 x 20.3 x 58.4

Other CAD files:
3D Renders/Design/Version 2/KAYODE_OLUWADAMISI_LOCIT-V2.stl

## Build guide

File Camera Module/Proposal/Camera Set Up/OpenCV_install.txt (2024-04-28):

Alright, so I'm struggling with the actual downloading of the OpenCV and importing cv2. I'm going to have to look into why the Raspberry Pi doesn't recognize the picam mod3 wide as an actual camera.

Additionally, I need to find a way to connect the servo motor to the two different picams running on individual Pi's. 

# | Terminal Command | Length of time to run
1	| sudo apt install cmake build-essential pkg-config git	a | few seconds
2	| sudo apt install libjpeg-dev libtiff-dev libjasper-dev libpng-dev libwebp-dev libopenexr-dev	| a few seconds
3	| sudo apt install libavcodec-dev libavformat-dev libswscale-dev libv4l-dev libxvidcore-dev libx264-dev libdc1394-22-dev libgstreamer-plugins-base1.0-dev libgstreamer1.0-dev	| 4 minutes
4	| sudo apt install libgtk-3-dev libqtgui4 libqtwebkit4 libqt4-test python3-pyqt5	| 4.5 minutes
5	| sudo apt install libatlas-base-dev liblapacke-dev gfortran	| 1 minute
6	| sudo apt install libhdf5-dev libhdf5-103	| 1 minute
7	| sudo apt install python3-dev python3-pip python3-numpy	| a few seconds

Installing Python 3.7
And all its packages to read the pic camera library for cv2
This process takes about 2 hours total

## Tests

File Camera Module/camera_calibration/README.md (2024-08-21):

# Camera Calibration Instructions

1. Create a folder named `calib_photos` inside the `camera_calibration` folder.
2. Print without any border adaptation, in an A4 paper sheet, the chessboard in the `pattern.png` file.
3. Attach the chessboard paper sheet to a planar/flat rigid surface, like a thick carboard piece or a clipboard.
4. With the desired camera/webcam, shoot various photos (20+) of the chessboard, with various angles.
5. Transfer all the photos to the `calib_photos` folder.
6. Ensure the `cameracalib.py` script has the correct path for the `calib_photos` folder.
7. The valid chessboard photos are visualized, after skipping them pressing a button, the camera coefficients are computed and printed out (may require some time).
8. Copy the camera parameters and save them to a file for late usage.

For further explanations, follow [this guide](https://learnopencv.com/camera-calibration-using-opencv/).

## Example
Camera parameters and distorsion coefficients in Python, initialized as numpy arrays

    camera_matrix = np.array([
        [899.12150372, 0., 644.26261492],
        [0., 899.45280671, 372.28009436],
        [0, 0,  1]
        ],
        dtype="double")

    dist_coeffs = np.array([
        [-0.03792548, 0.09233237, 0.00419088, 0.00317323, -0.15804257]
        ],
        dtype="double")

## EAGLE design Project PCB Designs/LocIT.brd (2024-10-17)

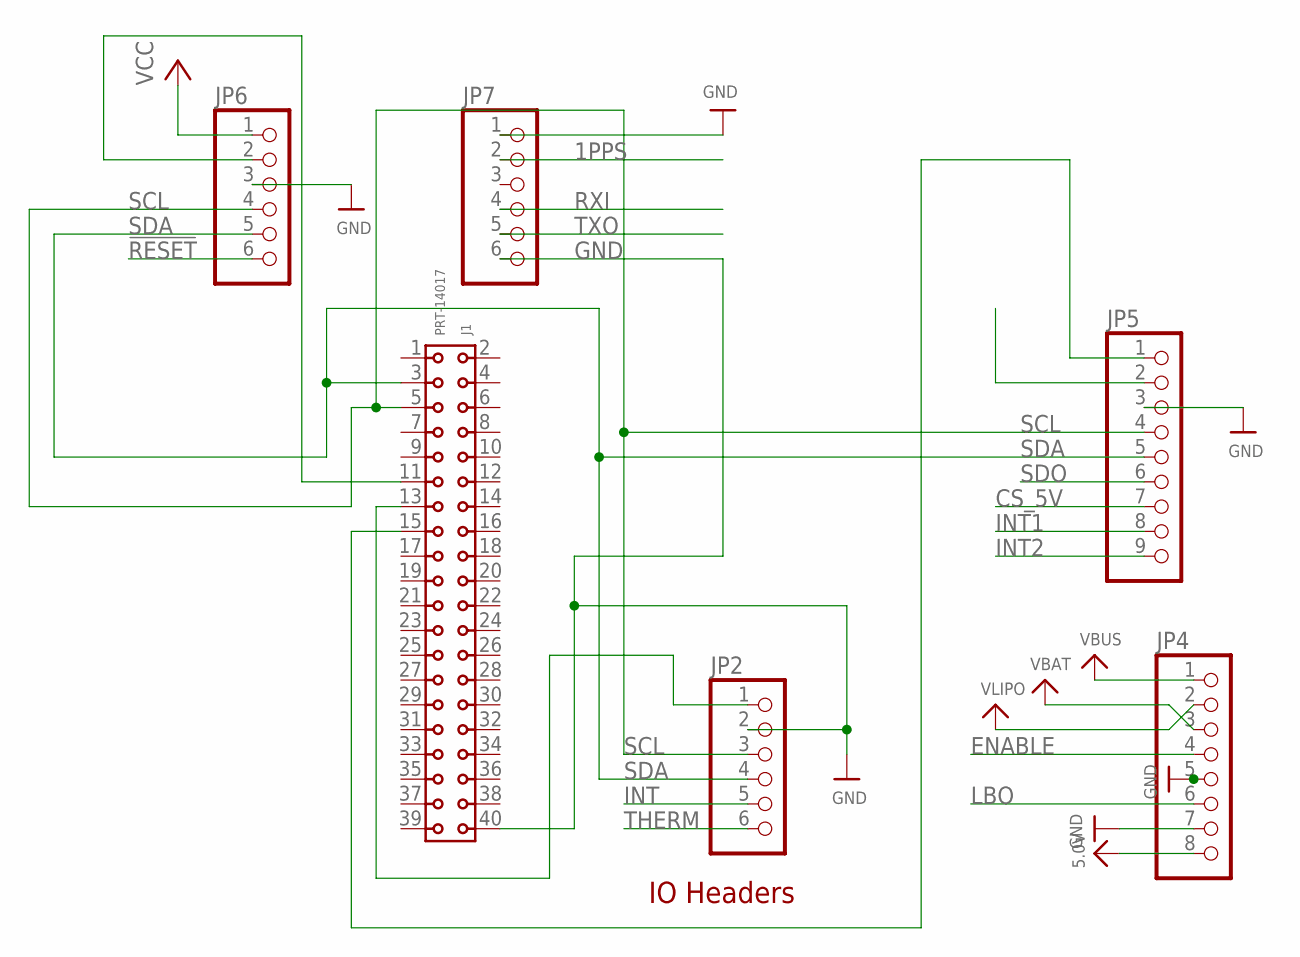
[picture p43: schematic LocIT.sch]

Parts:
J1: PRT-14017; 61304021821
JP2, JP6, JP7: HEADER-1X670MIL; 1X06_ROUND_70
JP4: HEADER-1X8ROUND; 1X08_ROUND
JP5: HEADER-1X970MIL; 1X09_ROUND_70

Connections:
1PPS: JP7.2
3.3V_GYRO: JP5.2
5.0V: JP4.8
!RESET: JP6.6
CS_5V: JP5.7
ENABLE: JP4.4
GND: J1.40, JP2.2, JP4.5, JP4.7, JP5.3, JP6.3, JP7.1, JP7.6
INT: JP2.5
INT1: JP5.8
INT2: JP5.9
LBO: JP4.6
unnamed: J1.11, JP6.2
RXI: JP7.4
SCL: J1.5, JP2.3, JP5.4, JP6.4
SDA: J1.3, JP2.4, JP5.5, JP6.5
SDO: JP5.6
THERM: JP2.6
TXO: JP7.5
VBAT: JP4.3
VBUS: JP4.1
VCC: JP6.1
VCC1: J1.13, JP2.1
VCC_GYRO: J1.15, JP5.1
VLIPO: JP4.2

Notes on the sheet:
IO Headers

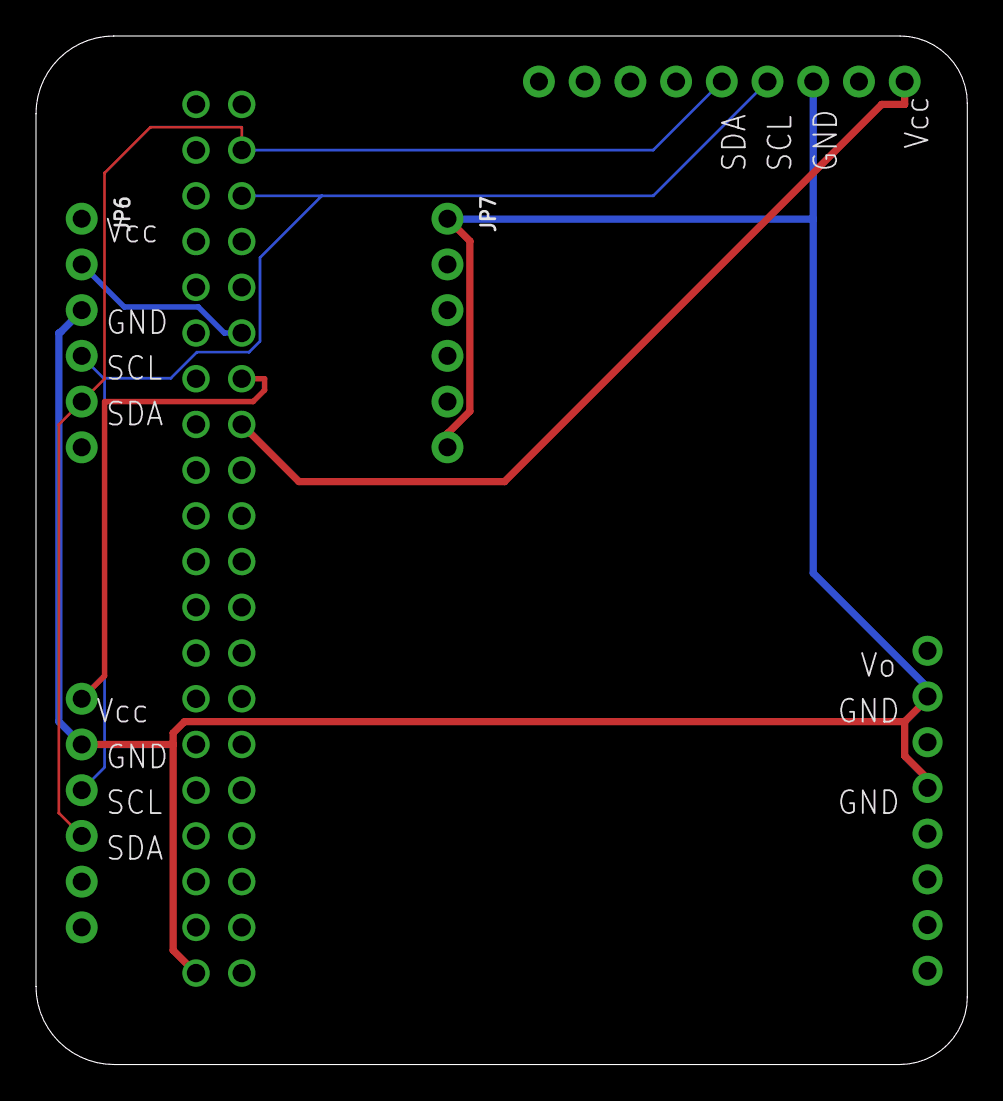
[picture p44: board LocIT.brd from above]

Board: 2 copper layers, 51.7 x 57.1 mm, 6 parts (1 on the bottom side), 6 nets.

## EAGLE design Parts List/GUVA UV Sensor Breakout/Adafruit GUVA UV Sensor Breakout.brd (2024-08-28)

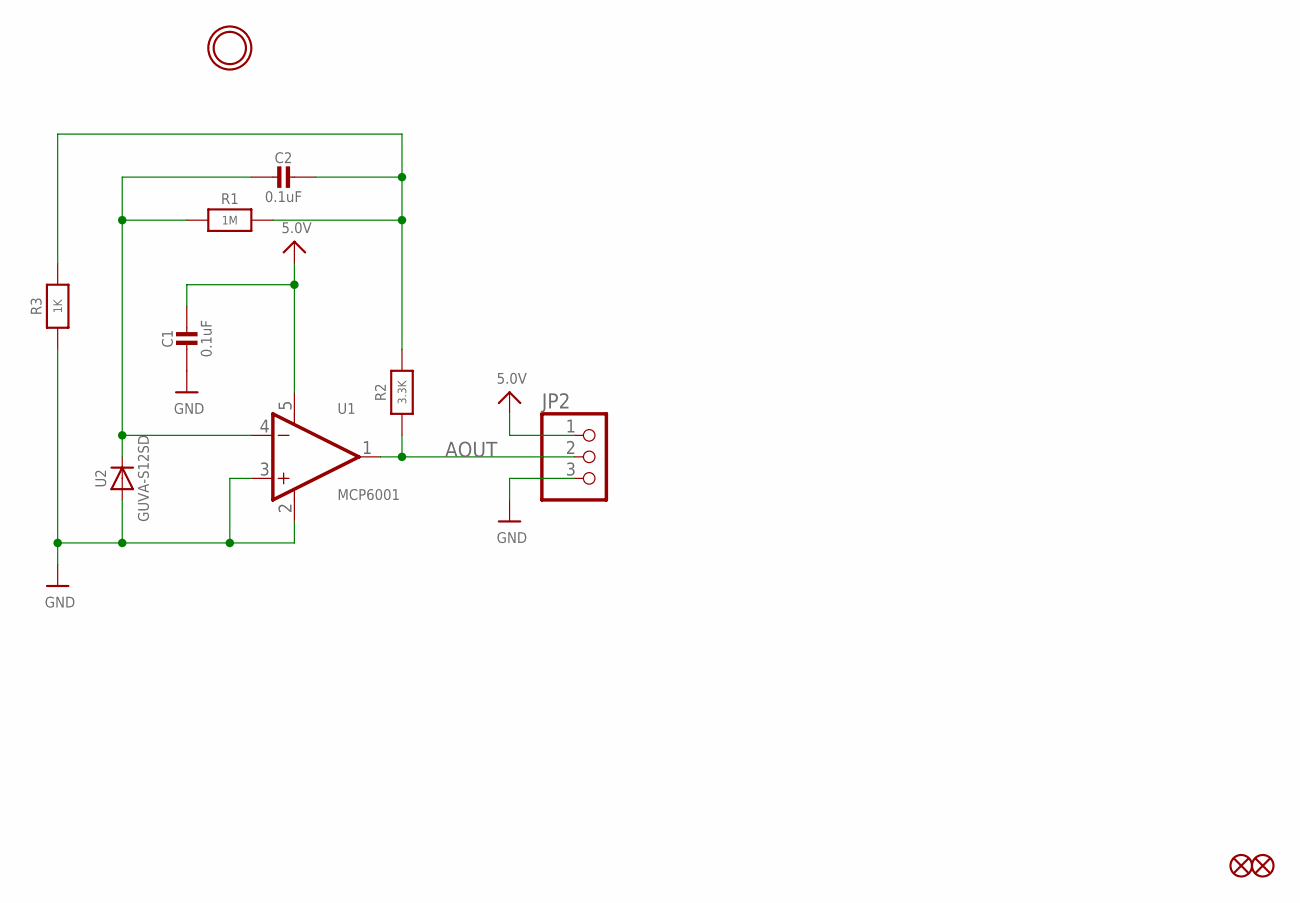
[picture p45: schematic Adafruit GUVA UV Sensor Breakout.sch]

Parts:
C1, C2: 0.1uF; 0805-NO
FID1, FID2: FIDUCIAL""; FIDUCIAL_1MM
JP2: PINHD-1X3CB; 1X03-CLEANBIG
R1: 1M; 0805-NO
R2: 3.3K; 0805-NO
R3: 1K; 0805-NO
U1: MCP6001; SOT23-5
U2: GUVA-S12SD
U$6: MOUNTINGHOLE2.5; MOUNTINGHOLE_2.5_PLATED

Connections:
5.0V: C1.1, JP2.1, U1.5 (V+)
AOUT: JP2.2, R2.1, U1.1 (OUT)
GND: C1.2, JP2.3, R3.1, U1.2 (V-), U1.3 (+IN), U2.A
unnamed: C2.1, R1.2, R2.2, R3.2
unnamed: C2.2, R1.1, U1.4 (-IN), U2.K (C)

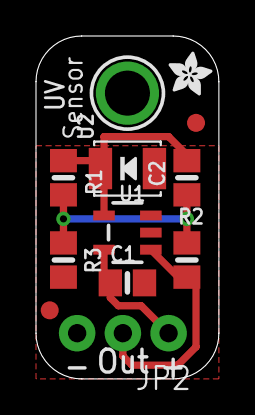
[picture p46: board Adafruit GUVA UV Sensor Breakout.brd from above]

Board: 2 copper layers, 10.2 x 19.1 mm, 13 parts (1 on the bottom side), 5 nets.

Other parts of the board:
U$7, U$8: ADAFRUIT_2.5MM

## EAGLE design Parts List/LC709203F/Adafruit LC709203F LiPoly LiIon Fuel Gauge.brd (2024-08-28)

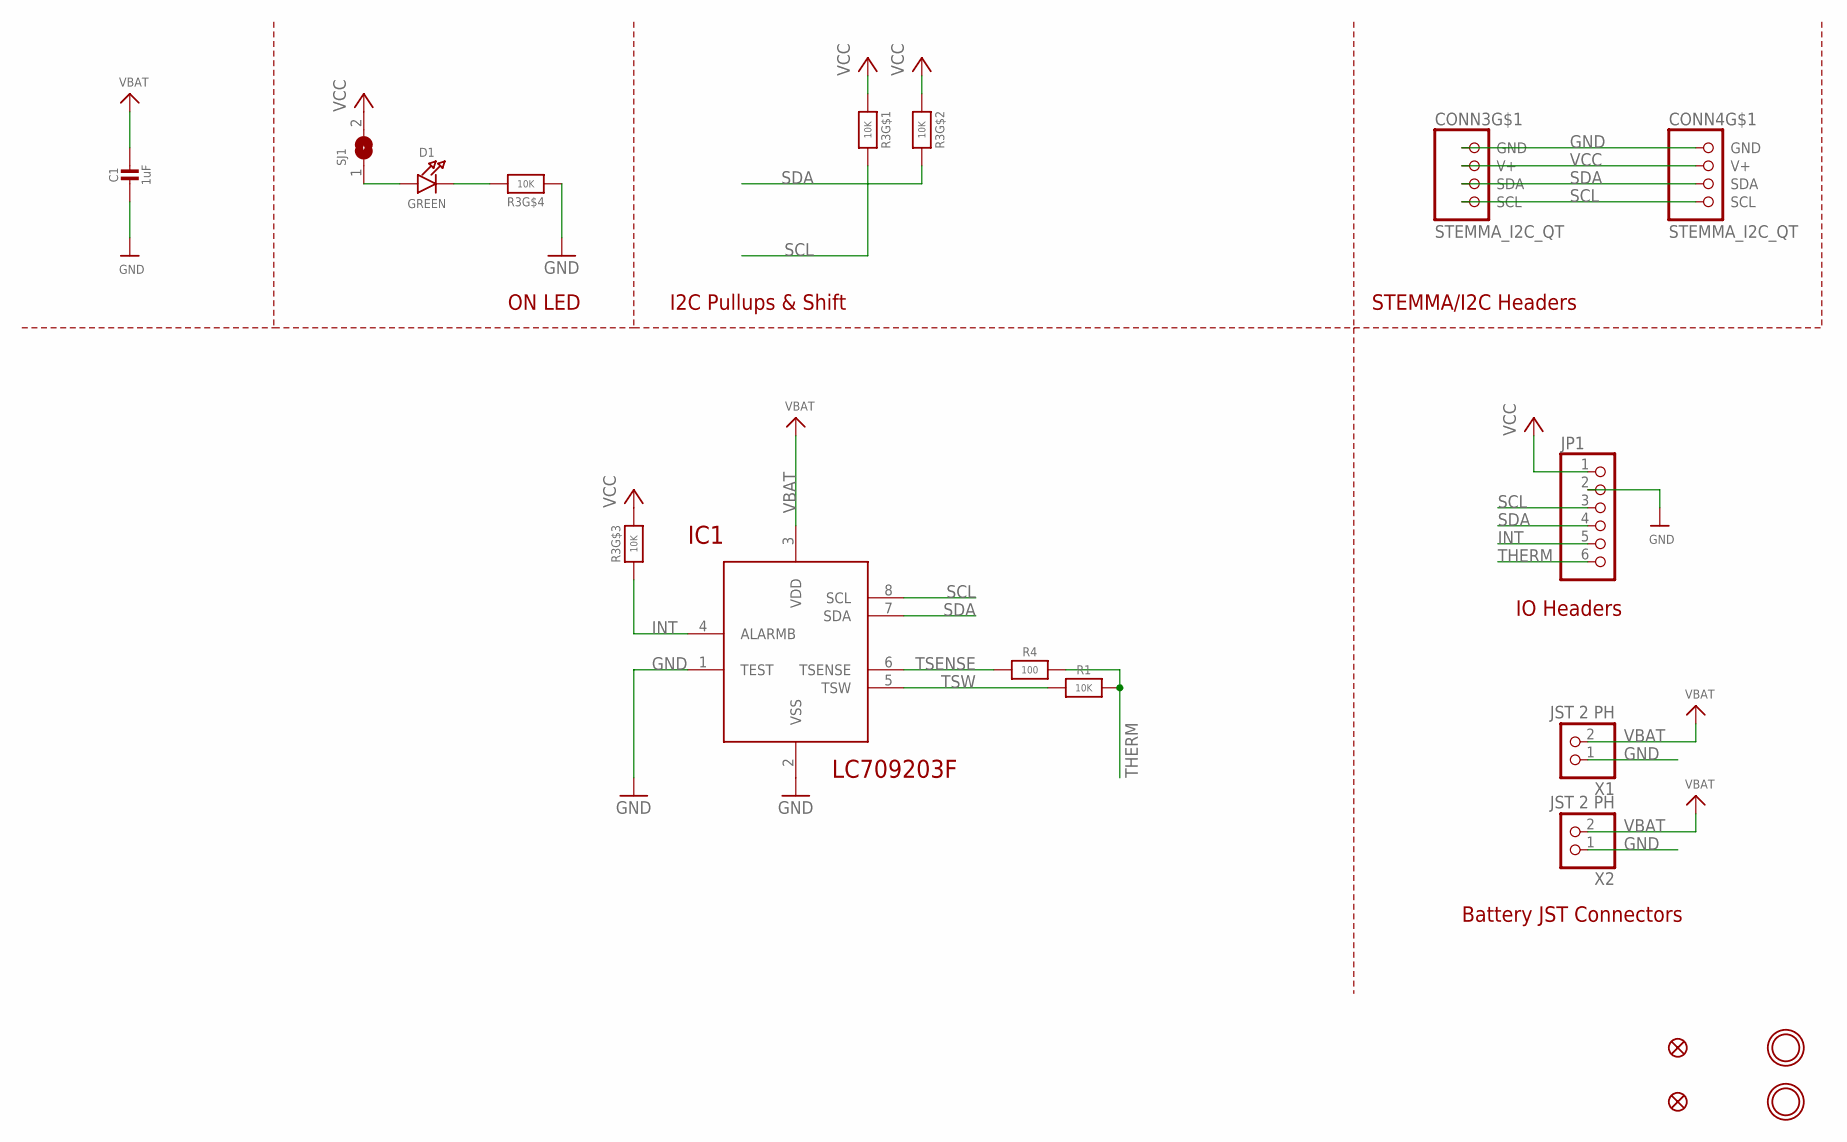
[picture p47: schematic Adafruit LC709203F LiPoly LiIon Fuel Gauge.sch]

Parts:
C1: 1uF; 0603-NO
CONN3, CONN4: STEMMA_I2C_QT; JST_SH4
D1: GREEN; CHIPLED_0603_NOOUTLINE
FID3, FID4: FIDUCIAL_1MM
IC1: LC709203F; WDFN8_3X4_0.65
JP1: HEADER-1X670MIL; 1X06_ROUND_70
R1: 10K; 0603-NO
R3: 10K; RESPACK_4X0603
R4: 100; 0603-NO
SJ1: SOLDERJUMPERCLOSED; SOLDERJUMPER_CLOSEDWIRE
U$19, U$21: MOUNTINGHOLE2.5; MOUNTINGHOLE_2.5_PLATED
X1, X2: JST 2 PH; JSTPH2_BATT

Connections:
GND: C1.2, CONN3.1 (GND), CONN4.1 (GND), IC1.1 (TEST), IC1.2 (VSS), JP1.2, R3.4 (1), X1.1, X2.1
INT: IC1.4 (ALARMB), JP1.5, R3.3 (1)
unnamed: D1.C, R3.5 (2)
unnamed: D1.A, SJ1.1
SCL: CONN3.4 (SCL), CONN4.4 (SCL), IC1.8 (SCL), JP1.3, R3.8 (2)
SDA: CONN3.3 (SDA), CONN4.3 (SDA), IC1.7 (SDA), JP1.4, R3.7 (2)
THERM: JP1.6, R1.2, R4.2
TSENSE: IC1.6 (TSENSE), R4.1
TSW: IC1.5 (TSW), R1.1
VBAT: C1.1, IC1.3 (VDD), X1.2, X2.2
VCC: CONN3.2 (V+), CONN4.2 (V+), JP1.1, R3.1, R3.2 (1), R3.6 (2), SJ1.2

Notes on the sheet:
I2C Pullups & Shift
STEMMA/I2C Headers
ON LED
Battery JST Connectors
IO Headers

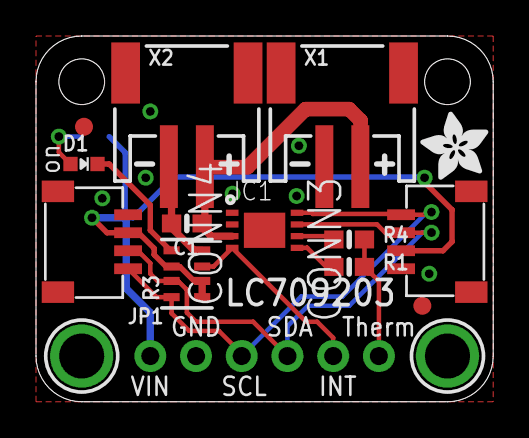
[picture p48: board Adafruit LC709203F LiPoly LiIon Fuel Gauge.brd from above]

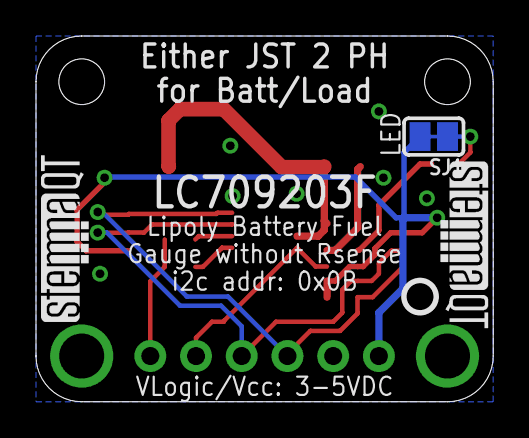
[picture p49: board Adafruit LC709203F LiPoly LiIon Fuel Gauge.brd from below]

Board: 2 copper layers, 25.4 x 20.3 mm, 20 parts (4 on the bottom side), 11 nets.

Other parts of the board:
U$22: ADAFRUIT_3.5MM
U$25: PCBFEAT-REV-040
U$30, U$31: STEMMAQT

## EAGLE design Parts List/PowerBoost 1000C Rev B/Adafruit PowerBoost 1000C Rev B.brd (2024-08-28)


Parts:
B1: JST 2-PH; JSTPH2
C1, C7, C8: 10uF; 0805-NO
C2: 2.2uF; 0805-NO
C4: 0.1uF; 0805_10MGAP
C6: 100uF; C1210
CHRG/LBO: ORANGE; CHIPLED_0805_NOOUTLINE
CN1: USBA_FEMALE; USB_HOST-PTH
CN4: MicroUSB; 4UCONN_20329
DONE: GREEN; CHIPLED_0805_NOOUTLINE
FID1, FID2, FID3: FIDUCIAL""; FIDUCIAL_1MM
JP2: HEADER-1X8ROUND; 1X08_ROUND
L1: 6.8uH; INDUCTOR_5X5MM_TDK_VLC5045
LED1: RED; CHIPLED_0805_NOOUTLINE
LED2: BLUE; CHIPLED_0805_NOOUTLINE
R1: 1.87M; _0805MP
R2: 340K; _0805MP
R3: 1.87M; 0805-NO
R4, R13: 200K; 0805-NO
R5, R8, R14, R20: 1K; 0805-NO
R6: 270K; 0805-NO
R7, R17: 100K; 0805-NO
R9: 43K; 0805-NO
R10: 49.9K; 0805-NO
R11: 75K 1%; 0805-NO
R12: 49.9K 1%; 0805-NO
R16: 1.0K; 0805-NO
T1: MMUN2133LT1G; SC59-BEC
THERM: 15K; 0805-NO
U1: TPS61090RSAR; PVQFN-16
U2: MCP73871; QFN20_4MM
U$10, U$11: MOUNTINGHOLE2.5; MOUNTINGHOLE_2.5_PLATED
X1: TERMBLOCK_1X2; TERMBLOCK_1X2-3.5MM

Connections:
5.0V: C2.1, C6.1, CN1.VBUS, JP2.8, R3.2, R5.1, R9.2, R11.2, U1.1 (VOUT), U1.15 (VOUT), U1.16 (VOUT), X1.2
D+: CN1.D+, R11.1, R12.1
D-: CN1.D-, R9.1, R10.1
ENABLE: JP2.4, R13.2, U1.11 (EN)
GND: B1.1 (-), C1.2, C2.2, C4.2, C6.2, C7.2, C8.2, CN1.GND, CN4.BASE@1 (GND), CN4.BASE@2 (GND), CN4.GND, CN4.SPRT@1 (GND), CN4.SPRT@2 (GND), CN4.SPRT@3 (GND), CN4.SPRT@4 (GND), JP2.5, JP2.7, LED1.C, LED2.C, R2.1, R4.1, R7.2, R10.2, R12.2, R16.1, R17.1, THERM.1, U1.5 (PGND), U1.6 (PGND), U1.7 (PGND), U1.10 (SYNC), U1.13 (GND), U1.P$18 (PGND), U1.P$19 (PGND), U1.P$20 (PGND), U1.P$21 (PGND), U1.P$22 (PGND), U1.THERMAL (PGND), U2.P$10 (VSS1), U2.P$11 (VSS2), U2.P$21 (THERMAL), X1.1
LBO: JP2.6, T1.B, U1.12 (LBO)
unnamed: L1.P$2 (2), U1.3 (SW), U1.4 (SW)
unnamed: LED1.A, R20.1
unnamed: R1.1, R2.2, U1.9 (LBI)
unnamed: LED2.A, R5.2
unnamed: R3.1, R4.2, U1.14 (FB)
unnamed: R20.2, T1.C
unnamed: R6.1, R7.1, U2.P$2 (VPCC)
unnamed: DONE.C, R14.2
unnamed: R14.1, U2.P$7 (STAT2)
unnamed: THERM.2, U2.P$5 (THERM)
unnamed: R8.1, U2.P$8 (STAT1/LBO)
unnamed: CHRG/LBO.C, R8.2
unnamed: R17.2, U2.P$12 (PROG3)
unnamed: R16.2, U2.P$13 (PROG1)
VBAT: C1.1, C4.1, JP2.3, L1.P$1 (1), R1.2, R13.1, T1.E, U1.8 (VBAT), U2.P$1 (VOUT1), U2.P$20 (VOUT2)
VBUS: C8.1, CHRG/LBO.A, CN4.VBUS, DONE.A, JP2.1, R6.2, U2.P$3 (SEL), U2.P$4 (PROG2), U2.P$9 (/TE), U2.P$17 (CE), U2.P$18 (VIN1), U2.P$19 (VIN2)
VLIPO: B1.2 (+), C7.1, JP2.2, U2.P$14 (VBAT1), U2.P$15 (VBAT2), U2.P$16 (VBATSENS)

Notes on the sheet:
Both grounds must be connected on the PCB at only one point close to the GND pin.
On/Off Switch
See Pg 15 1st para
6.8uH power w/2A current
R3 = 1.9Mohm for 5.2V R3 = 1.1Mohm for 3.3V
Charge Rate = 1000V/PROG1
1.0K = 1000mA
2.0K = 500mA
No Thermistor:
10K NTC Thermistor:
RT1 = 0, RT2 = 10K
RT1 = TBD, RT2 = TBD



Board: 2 copper layers, 36.1 x 22.9 mm, 47 parts (2 on the bottom side), 23 nets.

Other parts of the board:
U$12: PCBFEAT-REV-040
U$25: SYMBOL_PLUS
U$26: SYMBOL_MINUS
U$28: ADAFRUIT_5MM
U$45: ADAFRUIT_3.5MM

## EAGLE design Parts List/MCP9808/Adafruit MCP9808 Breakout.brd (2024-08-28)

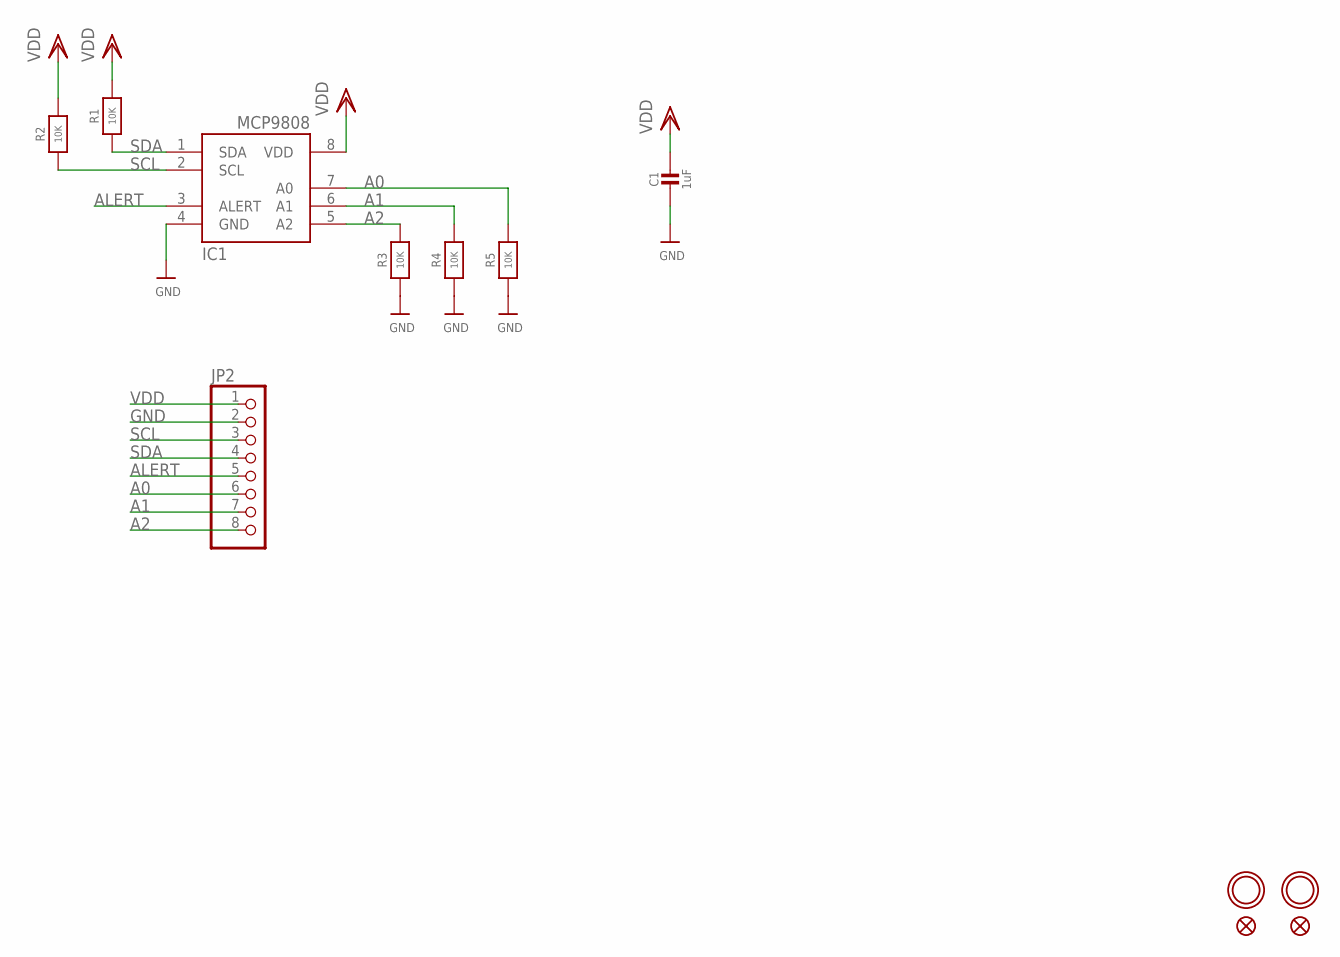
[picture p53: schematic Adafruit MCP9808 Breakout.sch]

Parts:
C1: 1uF; _0805MP
FID1, FID2: FIDUCIAL""; FIDUCIAL_1MM
IC1: MCP9808-E/MS; MSOP8_0.65MM
JP2: HEADER-1X870MIL; 1X08_ROUND_70
R1, R2, R3, R4, R5: 10K; 0805-NO
U$3, U$5: MOUNTINGHOLE2.5; MOUNTINGHOLE_2.5_PLATED

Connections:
A0: IC1.7 (A0), JP2.6, R5.2
A1: IC1.6 (A1), JP2.7, R4.2
A2: IC1.5 (A2), JP2.8, R3.2
ALERT: IC1.3 (ALERT), JP2.5
GND: C1.2, IC1.4 (GND), JP2.2, R3.1, R4.1, R5.1
SCL: IC1.2 (SCL), JP2.3, R2.1
SDA: IC1.1 (SDA), JP2.4, R1.1
VDD: C1.1, IC1.8 (VDD), JP2.1, R1.2, R2.2

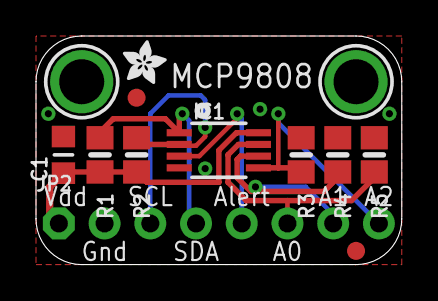
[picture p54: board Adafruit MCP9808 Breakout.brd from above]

Board: 2 copper layers, 20.3 x 12.7 mm, 13 parts (0 on the bottom side), 8 nets.

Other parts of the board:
U$4: ADAFRUIT_2.5MM

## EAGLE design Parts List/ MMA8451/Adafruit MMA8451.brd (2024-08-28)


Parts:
C1: 0.1uF; 0805-NO
C2, C3: 10uF; 0805-NO
C4: 0.1uF; 0805_10MGAP
FID1, FID2: FIDUCIAL""; FIDUCIAL_1MM
JP1: HEADER-1X870MIL; 1X08_ROUND_70
Q1, Q2: BSS138; SOT23-WIDE
R1, R2, R3, R4, R5: 10K; 0805-NO
U1: MMA8451; MMA845X_QFN_16MM
U2: MIC5225-3.3; SOT23-5
U$3, U$6: MOUNTINGHOLE2.5; MOUNTINGHOLE_2.5_PLATED

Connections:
+3V3: C1.1, C3.1, JP1.6, Q1.1 (G), Q2.1 (G), R3.2, R4.1, R5.2, U1.1 (VDDIO), U1.14 (VDD), U2.5 (OUT)
GND: C1.2, C2.2, C3.2, C4.2, JP1.7, U1.5 (GND), U1.10 (GND), U1.12 (GND), U2.2 (GND)
INT1: JP1.4, U1.11 (INT1)
INT2: JP1.5, U1.9 (INT2)
unnamed: C4.1, U1.2 (BYP)
SA0: JP1.1, R5.1, U1.7 (SA0)
SCL: JP1.3, Q1.3 (D), R1.1
SCL_3.3V: Q1.2 (S), R3.1, U1.4 (SCL)
SDA: JP1.2, Q2.3 (D), R2.2
SDA_3.3V: Q2.2 (S), R4.2, U1.6 (SDA)
VIN: C2.1, JP1.8, R1.2, R2.1, U2.1 (IN), U2.3 (EN)


Board: 2 copper layers, 20.3 x 17.8 mm, 19 parts (0 on the bottom side), 11 nets.

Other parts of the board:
U$10: ADAFRUIT_2.5MM

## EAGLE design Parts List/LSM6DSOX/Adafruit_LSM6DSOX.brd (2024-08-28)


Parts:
C1: 0.1uF; 0603-NO
C2, C3: 10uF; 0805-NO
CONN3, CONN4: STEMMA_I2C_QT; JST_SH4
D1: GREEN; CHIPLED_0603_NOOUTLINE
D2: 1N4148; SOD-323
FID3, FID4: FIDUCIAL_1MM
JP1: HEADER-1X970MIL; 1X09_ROUND_70
JP2: HEADER-1X570MIL; 1X05_ROUND_70
Q2: BSS138; SOT363
R2, R3: 10K; RESPACK_4X0603
SJ1: SOLDERJUMPER; SOLDERJUMPER_ARROW_NOPASTE
U2: AP2112K-3.3; SOT23-5
U$1, U$17: MOUNTINGHOLE2.5; MOUNTINGHOLE_2.5_PLATED
U$2: LSM6DSOX; LGA-14L

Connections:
3.3V: C1.1, C3.1, JP1.2, Q2.2 (G), Q2.5 (G), R2.1, R2.2 (1), R2.6 (2), R3.3 (1), R3.4 (1), R3.5 (2), SJ1.2, U2.5 (OUT), U$2.5 (VDDIO), U$2.8 (VDD)
CS_3V: D2.A, R3.6 (2), U$2.12 (CS)
CS_5V: D2.C, JP1.7
GND: C1.2, C2.2, C3.2, CONN3.1 (GND), CONN4.1 (GND), D1.C, JP1.3, JP2.1, R2.4 (1), U2.2 (GND), U$2.6 (GND), U$2.7 (GND)
INT1: JP1.8, U$2.4 (INT1)
INT2: JP1.9, U$2.9 (INT2)
unnamed: D1.A, R2.3 (1)
OCS_AUX: JP2.3, U$2.10 (OCS_AUX)
SCL: CONN3.4 (SCL), CONN4.4 (SCL), JP1.4, Q2.6 (D), R3.2 (1)
SCL_3V: Q2.1 (S), R2.8 (2), U$2.13 (SCL)
SCX: JP2.5, U$2.3 (SCX)
SDA: CONN3.3 (SDA), CONN4.3 (SDA), JP1.5, Q2.3 (D), R3.1
SDA_3V: Q2.4 (S), R2.7 (2), U$2.14 (SDA)
SDO: JP1.6, R2.5 (2), SJ1.1, U$2.1 (SDO)
SDO_AUX: JP2.2, U$2.11 (SDO_AUX)
SDX: JP2.4, U$2.2 (SDX)
VCC: C2.1, CONN3.2 (V+), CONN4.2 (V+), JP1.1, R3.7 (2), R3.8 (2), U2.1 (IN), U2.3 (EN)

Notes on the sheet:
I2C Pullups & Shift
STEMMA/I2C Headers
ON LED
Power supply



Board: 2 copper layers, 25.4 x 17.8 mm, 23 parts (4 on the bottom side), 17 nets.

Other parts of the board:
U$9: ADAFRUIT_2.5MM
U$25: PCBFEAT-REV-040
U$30, U$31: STEMMAQT

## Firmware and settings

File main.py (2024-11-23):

import GPSIoT
import TemperatureAWS
import BatteryAWS
import notificationAWS
import time
import json
from AWSIoTPythonSDK.MQTTLib import AWSIoTMQTTClient
import boto3
from datetime import datetime
from decimal import Decimal

# Initialize the DynamoDB client
dynamodb = boto3.resource('dynamodb', region_name='us-east-2')
table_name = 'LocIT'
table = dynamodb.Table(table_name)

# Global variables for overheat mode and low battery mode
overheat_mode = False
lowbattery_mode = False

def push_to_dynamodb(data):
    """Function to push combined data to DynamoDB."""
    try:
        # Convert all float values to Decimal
        data = {k: Decimal(str(v)) if isinstance(v, float) else v for k, v in data.items()}
        
        # Add the partition and sort keys
        data['sensorID'] = data.get('sensorID', 'combined_sensor')
        data['ts'] = int(time.time())  # Use the current epoch time as the sort key

        # Put item in DynamoDB
        table.put_item(Item=data)
        print("Successfully pushed data to DynamoDB:", data)
    except Exception as e:
        print(f"Error pushing data to DynamoDB: {e}")

def on_alert_message(client, userdata, message):
    """Callback for handling alert messages."""
    global overheat_mode, lowbattery_mode
    payload = message.payload.decode('utf-8')
    
    if payload == '1':  # Trigger alert only if payload is "1"
        if overheat_mode:
            print("Tracker currently overheated. Unable to send alert.")
        elif lowbattery_mode:
            print("Tracker currently in low battery mode. Unable to send alert.")
        else:
            print("Alert received. Activating alert callback...")
            notificationAWS.alert_callback(client, userdata, message)  # Trigger alert callback

def main():
    # AWS IoT Core settings
    host = "a25srdspphdz2u-ats.iot.us-east-2.amazonaws.com"
    certPath = "/home/avery119/certs/"
    clientId = "LocIT_RaspberryPi_Zero2W"

    # Init AWSIoTMQTTClient
    client = AWSIoTMQTTClient(clientId)
    client.configureEndpoint(host, 8883)
    client.configureCredentials(
        "{}RootCA1.pem".format(certPath),
        "{}LocIT_RaspberryPi_Zero2W.private.pem.key".format(certPath),
        "{}LocIT_RaspberryPi_Zero2W-cert.pem.crt".format(certPath)
    )

    # AWSIoTMQTTClient connection configuration
    client.configureAutoReconnectBackoffTime(1, 32, 20)
    client.configureOfflinePublishQueueing(-1)  # Infinite offline publishing
    client.configureDrainingFrequency(2)  # Draining: 2 Hz
    client.configureConnectDisconnectTimeout(20)  # 20 sec
    client.configureMQTTOperationTimeout(20)  # 20 sec

    print("Connecting to AWS IoT...")
    client.connect()
    print("AWS IoT Connected successfully!")

    # Subscribe to the "alert" topic to handle alerts
    client.subscribe("alert", 1, on_alert_message)
    
    while True:
        cnfg="config.txt"
        try:
          with open(cnfg, 'r') as file:
            for line in file:
                if "GeneralTimer" in line:
                    gT=line.strip()           
                    gT=gT.replace('GeneralTimer ', '')
                    gT=int(gT)
                if "LowPower" in line:
                    LP=line.strip()
                    LP=LP.replace('LowPower ', '')
        except:
          print("Can't open")
        try:
            # Get the latest temperature and overheat mode
            temp_data = TemperatureAWS.get_temperature(client)
            if temp_data:
                global overheat_mode
                overheat_mode = temp_data.get('overheat_mode', False)  # Update overheat_mode status
                print(f"Updated Overheat Mode: {'Active' if overheat_mode else 'Inactive'}")
            else:
                print("No temperature data received.")

            # Get the latest GPS data
            gps_data = GPSIoT.get_gps_data(client)
            if not gps_data:
                print("No GPS data received.")

            # Get the latest battery data and update lowbattery_mode
            battery_data = BatteryAWS.get_battery_power(client)
            if battery_data:
                global lowbattery_mode
                lowbattery_mode = battery_data.get('low_battery_mode', False)
                print(f"Updated Low Battery Mode: {'Active' if lowbattery_mode else 'Inactive'}")
            else:
                print("No battery data received.")
            
            if LP=="On":
              Low_Battery_Mode=True
            else:
              Low_Battery_Mode=False
            
            # Combine GPS, temperature, and battery data into one message if all are available
            if temp_data and gps_data and battery_data:
                combined_data = {
                    "timestamp": gps_data["timestamp"],
                    "sensorID": "combined_sensor",
                    "latitude": gps_data["latitude"],
                    "longitude": gps_data["longitude"],
                    "altitude_ft": gps_data["altitude_ft"],
                    "speed_mph": gps_data["speed_mph"],
                    "temperature_F": temp_data['temperature_F'],
                    "overheat_mode": temp_data['overheat_mode'],
                    "battery_voltage": battery_data['battery_voltage'],
                    "battery_percent": battery_data['battery_percent'],
                    "low_battery_mode": battery_data['low_battery_mode']
                }

                # Convert combined data to JSON and publish to AWS IoT
                messageJson = json.dumps(combined_data)
                print(f"Publishing to AWS IoT: {messageJson}")
                client.publish("combined", messageJson, 1)

                # Push the same data to DynamoDB
                push_to_dynamodb(combined_data)

            # Sleep for a while before the next loop iteration
            time.sleep(gT)

        except Exception as e:
            print(f"Error occurred: {str(e)}")
            break

if __name__ == "__main__":
    main()
    time.sleep(5)

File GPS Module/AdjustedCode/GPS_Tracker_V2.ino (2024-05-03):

const int GPSBaud = 4800;

#include <SPIFlash.h>

#if defined (ARDUINO_ARCH_AVR)
#define SerialMonitorInterface Serial
#include <SoftwareSerial.h>
#elif defined(ARDUINO_ARCH_SAMD)
#define SerialMonitorInterface SerialUSB
#include "SoftwareSerialZero.h"
#endif

// The chip/slave select pin is pin 5 for the Flash Memory TinyShield
const uint8_t flashCS = 5; 
unsigned long address = 0;

// The SPIFlash object for the chip. Passed the chip select pin in the constructor.
SPIFlash flash(flashCS); 

// The Arduino pins used by the GPS module
const uint8_t GPS_ONOFFPin = A3;
const uint8_t GPS_SYSONPin = A2;
const uint8_t GPS_RXPin = A1;
const uint8_t GPS_TXPin = A0;
const uint8_t chipSelect = 10;

// The GPS connection is attached with a software serial port
SoftwareSerial Gps_Serial(GPS_RXPin, GPS_TXPin);

// Set which sentences should be enabled on the GPS module
// GPGGA - 
char nmea[] = {'1'/*GPGGA*/, '0'/*GNGLL*/, '0'/*GNGSA*/, '0'/*GPGSV/GLGSV*/, '1'/*GNRMC*/, '0'/*GNVTG*/, '0'/*not supported*/, '0'/*GNGNS*/};

void setup()
{
  Gps_Serial.begin(GPSBaud);
  SerialMonitorInterface.begin(115200);
  if(!SerialMonitorInterface) { delay(5000);}; // Pauses 5 seconds if Serial Monitor is not opened

  SerialMonitorInterface.println("Initializing Flash Memory...");
  SerialMonitorInterface.println();
  pinMode(flashCS, OUTPUT); // Ensure chip select pin is an output.
  flash.begin(); // Boots the flash memory

  SerialMonitorInterface.println("Determining write/read start point...");
  uint8_t flashBuffer[256];
  uint8_t foundStart = false;
  while (!foundStart) {
    flash.readByteArray(address, flashBuffer, 256);
    int i;
    for (i = 0; !foundStart && i < 256; i++) {
      if (flashBuffer[i] == 0xFF) // checks for the first logical 1
        foundStart = true;
    }
    address += i;
  }
  address--;
  SerialMonitorInterface.println("Done.");
  SerialMonitorInterface.println();

  unsigned long timer = millis();
  SerialMonitorInterface.println("Send 'y' to start read mode. Write mode will begin in 10 seconds...");
  SerialMonitorInterface.println();
  while(millis() < timer + 10000) {
    if(SerialMonitorInterface.available()) {
      if(SerialMonitorInterface.read() == 'y') {
        readFlash(address);
      }
    }
  }

  SerialMonitorInterface.println("Now initiating write mode.");
  SerialMonitorInterface.println();

  // Init the GPS Module to wake mode
  pinMode(GPS_SYSONPin, INPUT);
  digitalWrite(GPS_ONOFFPin, LOW);
  pinMode(GPS_ONOFFPin, OUTPUT);
  delay(100);
  SerialMonitorInterface.print("Attempting to wake GPS module.. ");
  while (digitalRead( GPS_SYSONPin ) == LOW )
  {
    // Need to wake the module
    digitalWrite( GPS_ONOFFPin, HIGH );
    delay(5);
    digitalWrite( GPS_ONOFFPin, LOW );
    delay(100);
  }
  SerialMonitorInterface.println("done.");
  delay(100);

  char command[] = "$PSRF103,00,00,00,01*xx\r\n";
  for (int i = 0; i < 8; i++) {
    command[10] = i + '0';
    command[16] = nmea[i];
    int c = 1;
    byte checksum = command[c++];
    while (command[c] != '*')
      checksum ^= command[c++];
    command[c + 1] = (checksum >> 4) + (((checksum >> 4) < 10) ? '0' : ('A' - 10));
    command[c + 2] = (checksum & 0xF) + (((checksum & 0xF) < 10) ? '0' : ('A' - 10));
    Gps_Serial.print(command);
    delay(20);
  }

  SerialMonitorInterface.println();

}

void loop() {
  unsigned long startTime = millis();
  while (Gps_Serial.read() != '$') {
    //do other stuff here
  }
  while (Gps_Serial.available() < 5);
  Gps_Serial.read(); 
  Gps_Serial.read(); //skip two characters
  char c = Gps_Serial.read();
  //determine senetence type
  if (c == 'R' || c == 'G') {
    c = Gps_Serial.read();
    if (c == 'M') {
      logNMEA(1);
    } else if (c == 'G') {
      logNMEA(2);
    }
  }

  // Waits 10 seconds before reading next NMEA string
  while (millis() - startTime < 10000) {
    Gps_Serial.read(); // clears GPS serial buffer
  }
}

void logNMEA(uint8_t type) {
  uint8_t buffer[82];
  // Initializes buffer to null terminators to ensure proper writing to flash memory
  for(int i = 0; i < 82; ++i) {
    buffer[i] = '\0';
  }

    // Writes NMEA string to buffer
  buffer[0] = '$';
  int counter = 1;
  char c = 0;
  while (!Gps_Serial.available());
  c = Gps_Serial.read();
  while (c != '*') {
    buffer[counter++] = c;
    while (!Gps_Serial.available());
    c = Gps_Serial.read();
  }
  buffer[counter++] = c;
  while (!Gps_Serial.available());
  c = Gps_Serial.read();
  buffer[counter++] = c;
  while (!Gps_Serial.available());
  c = Gps_Serial.read();
  buffer[counter++] = c;
  buffer[counter++] = '\r';
  buffer[counter++] = '\n';

  buffer[2] = 'P'; // Changes GNRMC to GPRMC

  c = 1;
  byte checksum = buffer[c++];
  while (buffer[c] != '*')
    checksum ^= buffer[c++];
  buffer[c + 1] = (checksum >> 4) + (((checksum >> 4) < 10) ? '0' : ('A' - 10));
  buffer[c + 2] = (checksum & 0xF) + (((checksum & 0xF) < 10) ? '0' : ('A' - 10));

  // Writes buffer array to flash memory. Write length is variable to maximize memory.
  flash.writeCharArray(address, (char *)buffer, strlen((char *)buffer));
  address += strlen((char *)buffer); // Sets address ahead for length of the nmea string
}

void readFlash(unsigned long address) {
  char command;
  do {
    // Clear Serial write buffer to prepare for read
    while(SerialMonitorInterface.available()) {
      SerialMonitorInterface.read();
    }
    // Menu
    SerialMonitorInterface.println("Read Mode | Please select a command (1, 2, 3):");
    SerialMonitorInterface.println("1. Read to serial monitor.");
    SerialMonitorInterface.println("2. Erase all data.");
    SerialMonitorInterface.println("3. Exit read mode.");
    while(!SerialMonitorInterface.available());
    command = SerialMonitorInterface.read();
    // Command select
    switch(command) {
      case '1':
        // Handles empty flash
        if(address == 0) {
          SerialMonitorInterface.println("No available data.");
          SerialMonitorInterface.println();
        } else {
          // Reads all available data to the Serial monitor
          for(unsigned long i = 0; i < address; ++i) {
            SerialMonitorInterface.print((char)flash.readChar(i));
          }
          SerialMonitorInterface.println();
        }
        break;
      case '2':
        // Erases data up until the first available byte.
        eraseData(address);
        address = 0; // resets the first available byte address to 0
        SerialMonitorInterface.println("All data erased.");
        SerialMonitorInterface.println();
        break;
      case '3':
        // Exits read mode.
        return;
      default:
        // Passes by invalid input.
        SerialMonitorInterface.println("That is not a recognized command.");
        SerialMonitorInterface.println();
        break;  
    }
  } while(command != 3);
}
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

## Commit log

2024-08-28 Create Adafruit MMA8451.brd
    [Adafruit MMA8451.brd]
2024-08-28 Create Adafruit MMA8451.sch
    [Adafruit MMA8451.sch]
2024-08-28 Create Adafruit MCP9808 Breakout.brd
    [Adafruit MCP9808 Breakout.brd]
2024-08-28 Create Adafruit MCP9808 Breakout.sch
    [Adafruit MCP9808 Breakout.sch]
2024-08-28 Create Adafruit PowerBoost 1000C Rev B.brd
    [Adafruit PowerBoost 1000C Rev B.brd]
2024-08-28 Create Adafruit PowerBoost 1000C Rev B.sch
    [Adafruit PowerBoost 1000C Rev B.sch]
2024-08-28 Create Adafruit LC709203F LiPoly LiIon Fuel Gauge.brd
    [Adafruit LC709203F LiPoly LiIon Fuel Gauge.brd]
2024-08-28 Create Adafruit LC709203F LiPoly LiIon Fuel Gauge.sch
    [Adafruit LC709203F LiPoly LiIon Fuel Gauge.sch]
2024-08-28 Create Adafruit GUVA UV Sensor Breakout.brd
    [Adafruit GUVA UV Sensor Breakout.brd]
2024-08-28 Create Adafruit GUVA UV Sensor Breakout.sch
    [Adafruit GUVA UV Sensor Breakout.sch]
2024-09-09 Create RaspberryPi
    This is the code that will be utilized for the GPS Tracker for the Raspberry Pi.
2024-09-09 Create Notification Alert Driver
2024-09-16 Rename Camera Module/Camera Set Up/FacialExpressions.txt to Camera Module/Proposal/Camera Set Up/FacialExpressions.txt
2024-09-16 Rename Camera Module/Camera Set Up/OpenCV_install.txt to Camera Module/Proposal/Camera Set Up/OpenCV_install.txt
2024-09-16 Update and rename Camera Module/camera_calibration/README.md to Camera Module/Proposal/camera_calibration/README.md
2024-09-16 Update and rename Camera Module/camera_calibration/cameracalib.py to Camera Module/Proposal/camera_calibration/cameracalib.py
2024-09-16 Update and rename Camera Module/camera_calibration/parameters.txt to Camera Module/Proposal/camera_calibration/parameters.txt
    [parameters.txt]
2024-09-16 Rename Camera Module/camera_calibration/pattern.png to Camera Module/Proposal/camera_calibration/pattern.png
2024-09-16 Rename Camera Module/docs/5Mohl.jpg to Camera Module/Proposal/docs/5Mohl.jpg
2024-09-30 Add files via upload
    STL file of the first 3D printed prototype, consists of the body and a cover
    [KAYODE_DAMISI_LOCITBODY-version1.stl, KAYODE_DAMISI_LOCITCOVER-version1.stl]
2024-09-30 Delete Camera Module/Facial_Recognition_PC/names.json
    not necessary for the main files to work (just how names are saved as lists are implemented in this file)
2024-09-30 Add files via upload
    Overview of the current UI/UX app for the LocIT app.
2024-09-30 Create Flutterflow App Preview Link
    Heres the link to preview the current app in Flutterflow
2024-10-23 Create BatteryAWS.py
    First attempt at the battery AWS with lowBattery.
2024-11-06 update files for pi camera
2024-11-21 added folders and new stl files for milestone 3
    [Anindita Senior Design (Body).STL, Anindita Senior Design (Lid).STL, KAYODE_DAMISI_LOCITBODY-version1.stl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]

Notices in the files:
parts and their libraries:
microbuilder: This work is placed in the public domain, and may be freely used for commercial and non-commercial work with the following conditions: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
